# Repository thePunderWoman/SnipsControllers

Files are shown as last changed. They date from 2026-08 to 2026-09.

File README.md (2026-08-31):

<p align="center">
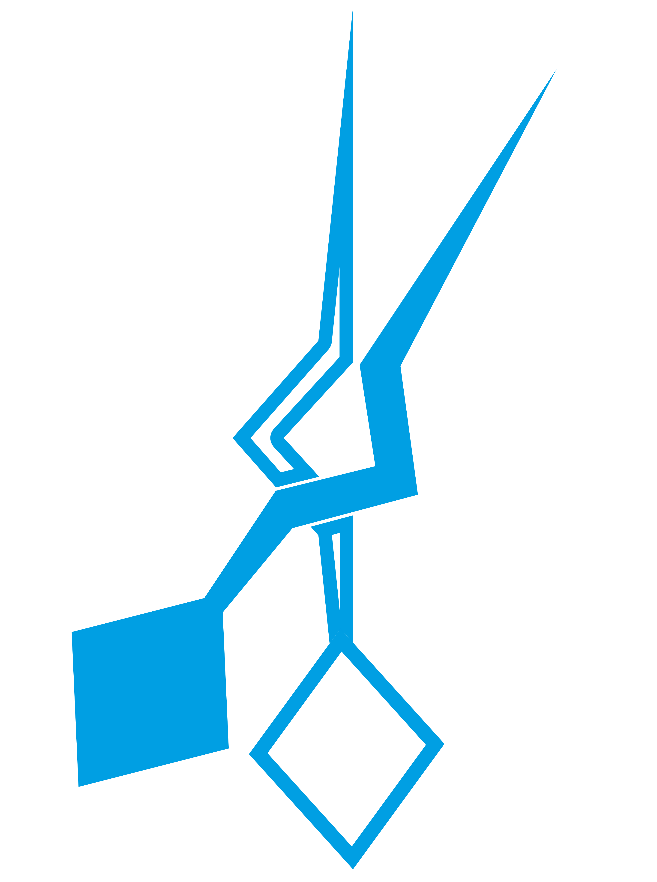
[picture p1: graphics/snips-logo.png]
Snips Controllers logo
  
</p>

<h1 align="center">The Snips Controllers</h1>

<p align="center">
  Wireless handheld controllers for R2-D2 droid operation, built to work with the
  <a href="https://github.com/thePunderWoman/Amidala">Amidala</a> control system and firmware.
</p>

<p align="center">
  <a href="https://github.com/thePunderWoman/SnipsControllers/actions/workflows/ci.yml">
    
  </a>
</p>

## Status

**Awaiting prototype PCBs.**

Schematics, part matching, and layout review are complete; boards are in the ordering/fab pipeline. See [PCB/README.md](PCB/README.md) for the full hardware writeup and [PCB/design-review-2026-08-23.md](PCB/design-review-2026-08-23.md)
for the latest design review. PCBs will likely arrive middle to late September. Once the controllers have been validated, we'll start ordering larger runs and make them available for people to buy.

## What they are

The Snips controllers are dual small handheld controllers for driving your droid
builds. These controllers are intended to be small, but powerful controllers that
can be configured via Amidala to do whatever you prefer to do.

## What they offer

Each Snips controller offers 6 face buttons, 2 side buttons on each side, 1 bumper
button, and a precision hall effect analog trigger. They utilize standard thumbsticks
and are specifically designed to work with either gulikit hall effect or tmr kits,
making sure you have no stick drift over time.

Combining all buttons, including center stick, that's 13 button options per controller. Plus, through Amidala each button can support regular press, alt button press, double press, and long press. All told, you have currently up to **52** different programmable options per controller!

Each controller also has a small OLED screen just above the thumbsticks for as much
info as you'd like to see, like power levels, which hand the controller is for, which
droid, volume levels, etc.

## Communication

These controllers are designed to work with Xbee3 modules for long distance secure
communication, but also, since they are powered by ESP32-S3-WROOM-1 modules, they also
support bluetooth and ESP-Now for connectivity. They will be able to swap between droids, as well.

## Batteries

We're still working on the exact battery spec, but they will either be swappable single 18650 or dual 14500 lithium ion modules. The controllers have a built in charging circuit. So you can charge them via USB-C, or just plain swap mid-event if they run out.

## Case

The controller case, aka how it looks and feels in the hand is still to be designed, but will be open source, allowing you to make it as unique to your build as you'd like.

## Estimated price

This is yet to be determined since we're so early in the prototype stage, but the pricing will be fully transparent. We will likely try to bundle two controllers with an Amidala board, and hopefully close to at cost with a small donation to charity included.

## Repository layout

| Path | Contents |
|---|---|
| [`src/`](src) | ESP32-S3 firmware (PlatformIO) |
| [`test/`](test) | Native unit tests (no hardware required) |
| [`PCB/`](PCB) | KiCad schematics, layout, GPIO reference, and design notes |
| [`scripts/`](scripts) | BOM/part-matching tooling |

## Development

Requires [PlatformIO](https://platformio.org/) (CLI or IDE extension).

```bash
# Build the firmware
pio run

# Run unit tests (no hardware required)
pio test -e native
```

See [CONTRIBUTING.md](CONTRIBUTING.md) for the full contribution workflow.

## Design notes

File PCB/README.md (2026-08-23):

# Snips Controller PCB

A wireless handheld controller for R2-D2 droid operation, designed for use at public events and conventions. Communicates with the droid via XBee3 Zigbee radio in a packetized state-report architecture.

## Hardware Overview

| Component | Part | Notes | Layout diagram |
|---|---|---|---|
| MCU | ESP32-S3-WROOM-1 module | Pre-certified: integrated flash, crystal, WiFi/BT radio + antenna. Same MCU family as Amidala. See `GPIO_table.md` for the full support circuitry | — |
| Display | SSD1306 1.3" OLED | 128x64, monochrome, I2C | — |
| Radio | XBee3 | Zigbee, SPI mode, THT socket (proto) | — |
| Hall trigger | DRV5055A2 | Ratiometric linear hall effect, 3.3V | — |
| Thumbstick | GuliKit hall effect module | Native 3.3V, analog X/Y + click | — |
| Buttons | Omron B3F series | Tactile momentary clicky | — |
| RGB LED | SK6812 NeoPixel-compatible | RMT-driven, 3.3V native, single LED status indicator | — |
| Charger | bq25185 | USB/DC input, power path, 4.2V/500mA | [diagram](diagrams/power_charger_layout.md) |
| Buck | TLV62569 | 3.3V output, 1A | [diagram](diagrams/power_buck_layout.md) |
| Battery | 18650 or 14500 Li-ion | Swappable single cell, TBD empirically | — |
| Power switch | DMG2305UX + 2N7002 | Soft latch, hybrid hardware+firmware | [diagram](diagrams/power_control_layout.md) |

## Layout Diagrams

Suggested top-copper floorplans for the three sheets with real layout
stakes — a switching regulator, a linear charger with a thermal pad, and
the transistor carrying the whole board's current. Each is checked
against the actual component datasheet, not just the schematic. See
[`diagrams/README.md`](diagrams/README.md) for the full list and how the
files are organized.

- [Buck converter](diagrams/power_buck_layout.md) — `power_buck.kicad_sch`
- [Charger](diagrams/power_charger_layout.md) — `power_charger.kicad_sch`
- [Power latch](diagrams/power_control_layout.md) — `power_control.kicad_sch`

## GPIO Assignment

> See `GPIO_table.md` for the full pin-by-pin table, including
> ESP32-S3-WROOM-1 support circuitry — this section is a summary.

### Reserved — Do Not Use
| Pin | Reason |
|---|---|
| 1, 40, 41 | GND |
| 2 | 3V3 |
| 3 (EN) | Reset/enable, pulled up via R_EN_PU |
| 13 (USB_D-) | Native USB |
| 14 (USB_D+) | Native USB |
| 27 (GPIO0/BOOT) | Boot strapping pin, pulled up via R_BOOT_PU + button |
| 26-32 (internal) | Internal SPI flash — not present on this module at all |
| 33-34 (internal) | Not broken out on the WROOM-1 module |
| 8 (GPIO15) | XBee SPI_ATTN — data-ready interrupt |
| 22 (GPIO18) | XBee ON_SLEEP status input |

Usable with care (strapping pins, sampled at boot): 15 (GPIO3), 16 (GPIO46), 26 (GPIO45).
Clean spares (default JTAG): 34-35 (GPIO41-42). 32/33 from the same group are used by BTN_VOL_DN/BTN_VOL_UP.

The module integrates the WiFi/BT radio, antenna, flash, and crystal
internally — no external wireless component, no bit-banged interface
consuming GPIO, unlike the bare-RP2350A design this replaced.

### SPI (XBee)
| Function | Pin |
|---|---|
| XBee SCK | 18 |
| XBee MOSI | 19 |
| XBee MISO | 20 |
| XBee CS | 21 |
| XBee ON_SLEEP | 22 |
| XBee SPI_ATTN | 8 |

### I2C (OLED)
| Function | Pin |
|---|---|
| SDA | 12 |
| SCL | 17 |

### ADC — ADC1 only (ADC2 is unusable while WiFi is active)
| Function | Pin |
|---|---|
| Analog trigger (DRV5055) | 4 |
| Thumbstick X (GuliKit) | 5 |
| Thumbstick Y (GuliKit) | 6 |
| VSYS battery sense | 7 |

### Digital Inputs / Outputs
| Function | Pin | Notes |
|---|---|---|
| Vol up | 33 | Active low, internal pull-up |
| Vol down | 32 | Active low, internal pull-up |
| Trigger up (mirrored VOL pair, opposite-handed variant) | 9 | Active low, internal pull-up |
| Trigger down (mirrored VOL pair, opposite-handed variant) | 10 | Active low, internal pull-up |
| Digital trigger (bumper) | 11 | Active low, internal pull-up |
| Thumbstick click (KEY) | 23 | Active low, internal pull-up |
| Macro buttons 1-6 | 24, 25, 28, 29, 30, 31 | Active low, internal pull-up — direct-wired, no scan matrix |
| Power button sense | 38 | Input, 3-second hold detect |
| Charge status STAT1 | 39 | Open-drain, 10kΩ pull-up to 3V3 |
| Power latch hold | 36 | Output, HIGH on boot to hold latch |
| RGB LED DIN (SK6812) | 37 | RMT-driven |

### Macro Buttons — Direct-Wired, No Scan Matrix
6 macro buttons, each on its own GPIO with an internal pull-up. No
anti-ghosting diodes or scan firmware needed — ESP32-S3-WROOM-1 has
enough spare GPIO (roughly 8) that the 1-pin savings a 2x3 matrix would
give isn't worth the added complexity, unlike the bare-RP2350A design
(only 1 spare pin) this replaced.

### Spare GPIO
Pins 34-35 (default JTAG, clean) and 15/16/26 (strapping, usable with care).
32/33 from the same JTAG group are used by BTN_VOL_DN/BTN_VOL_UP.

---

## MCU Support Circuitry (ESP32-S3-WROOM-1)

Far simpler than the bare-RP2350A design it replaced — the module
integrates flash, crystal, and the WiFi/BT radio + antenna internally.
What's left: EN pull-up, BOOT pull-up + button, USB series resistors,
3V3 decoupling, and the VSYS battery-sense divider — all standard
ESP32-S3 practice, matching Espressif's own reference designs. See
`GPIO_table.md` for the full component list.

**No longer needed at all:** external QSPI flash chip, crystal + load
caps, core-regulator LC filter, ADC_AVDD RC filter, per-pin IOVDD/DVDD
decoupling network, separate wireless module + its bit-banged interface
+ antenna licensing question.

> **Layout note:** the module's footprint includes the required antenna
> keepout area — keep copper/components out of it per the module's
> datasheet. Much simpler than a custom PCB trace antenna, but still a
> real layout-stage requirement.

---

## Passives & Support Components

### Decoupling Caps
| Component | Value | Notes |
|---|---|---|
| DRV5055 VCC | 100nF ceramic | Close to supply pin |
| GuliKit VCC | 100nF ceramic | Close to supply pin |
| SK6812 VCC | 100nF ceramic | Close to supply pin |
| bq25185 VIN | 10µF + 100nF ceramic | X7R/X5R, 25V rated |
| bq25185 SYS | 10µF + 100nF ceramic | X7R/X5R, 25V rated |
| bq25185 BAT | 10µF ceramic | |
| TLV62569 VIN | 10µF ceramic | |
| TLV62569 VOUT | 22µF ceramic | |
| ESP32-S3-WROOM-1 3V3 | 10µF + 100nF ceramic | Standard module decoupling |

### Pull-up Resistors
| Signal | Value | Notes |
|---|---|---|
| bq25185 STAT1 | 10kΩ | Open-drain, pull up to 3V3 |
| bq25185 TS/MR | 10kΩ to GND | REQUIRED if no thermistor — floating = no charging |
| XBee RESET | 10kΩ to 3V3 | Plus 100Ω + 100nF RC filter at pin |
| I2C SDA/SCL | 4.7kΩ | **DNP for prototyping** — Adafruit #938 has onboard pull-ups. Populate only on final PCB with bare OLED panel |
| ESP32-S3 EN | 10kΩ to 3V3 | Reset/enable |
| ESP32-S3 GPIO0/BOOT | 10kΩ to 3V3 | Plus button to GND to force UF2/download mode |

### Series Resistors
| Signal | Value | Notes |
|---|---|---|
| SK6812 DIN (pin 37) | 300–500Ω | Signal integrity, place close to pad |
| USB D+/D- (pins 13/14) | 27Ω | Between module and external USB-C connector |

### Direct Buttons (all of them — no matrix)
No external components needed. Wire to GND; enable ESP32-S3 internal
pull-ups in firmware. Applies to vol up/down, digital trigger, stick
click, and all 6 macro buttons.

### XBee
Refer to AmidalaShield V1.2 for XBee3 support circuitry. THT socket for prototyping; update footprint to SMT module for final PCB if size requires.

Beyond the 4-wire SPI bus (SCK/MOSI/MISO/CS) and RESET, three more pins are
wired per Amidala's actual netlist: DTR tied to GND, ON_SLEEP and SPI_ATTN
to pins 22/8. SPI_ATTN in particular is the XBee's data-ready interrupt —
needed for reliable SPI transfers, not just a nice-to-have.

---

## Communication Architecture

Controllers communicate with the droid via XBee3 in **packetized state-report** mode. The ESP32-S3 firmware reads all inputs locally (button states, ADC values for analog trigger and thumbstick) and assembles them into a structured payload transmitted periodically over SPI to the XBee3 radio. The receiving AmidalaShield deserializes the packet and interprets controller state.

This approach is preferred over per-signal transmission as it is more efficient, easier to deserialize, and robust to timing issues.

### Network Configuration
- Each droid has its own coordinator with a unique PAN ID
- All coordinators share the same AES encryption key
- Controllers are configured as routers
- "Switch droid" functionality is implemented via XBee API commands to leave the current network and rejoin a different PAN ID on demand
- Active droid name and connection status are shown on the OLED display

---

## Bringup Sequence

Recommended bringup order:
1. ESP32-S3-WROOM-1 alone — verify USB enumeration, flash blink sketch, confirm pin 36 latch hold works
2. OLED on I2C — verify I2C on pins 12/17, get something on screen
3. SK6812 RGB LED — verify RMT output on pin 37, cycle colors
4. Buttons — verify direct inputs on pins 9/10/11/23 and all 6 macro buttons (pins 24/25/28/29/30/31)
5. Charge status — verify STAT1 on pin 39 reads correctly
6. DRV5055 + GuliKit thumbstick — verify ADC1 readings on pins 4/5/6
7. XBee over SPI — verify basic communication

---

## Power Architecture

- Battery → bq25185 (charger + power path, 4.2V VBATREG, 500mA) → TLV62569 (3.3V buck) → ESP32-S3-WROOM-1 3V3 and all 3.3V logic
- Power switch: soft latch (DMG2305UX PFET + 2N7002 NFET) controls TLV62569 EN pin
- Boot: press power button → hardware latch enables 3V3 → ESP32-S3-WROOM-1 boots → pin 36 driven HIGH to hold latch
- Shutdown: firmware detects 3-second hold on pin 38 → graceful shutdown → pin 36 LOW → power cut
- bq25185 STAT1 → pin 39 (open-drain, 10kΩ pull-up to 3V3)
- Battery voltage sense → pin 7 via external R_VSYS1/R_VSYS2 divider (reads VSYS/3 via ADC1)
- All logic is 3.3V native — ESP32-S3-WROOM-1, DRV5055, GuliKit thumbstick, SK6812

No firmware ADC-gating workaround needed for battery sense — WiFi is
fully on-die on ESP32-S3 and doesn't share any exposed GPIO/ADC path
with the VSYS sense pin, unlike the old bit-banged RP2350+CYW43439
design.

## Power Management

Firmware implements tiered power saving:
- **Active**: full brightness OLED, normal polling rate
- **Idle (short timeout)**: OLED dimmed via SSD1306 contrast command
- **Idle (long timeout)**: OLED off
- **Sleep**: MCU sleep, wake on any button press via GPIO interrupt

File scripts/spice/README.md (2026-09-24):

# SPICE check for the Power_Control soft-latch

`latch_sim.py` simulates the button, inverter, diode-OR, latch FET and power PMOS from
`PCB/power_control.kicad_sch` and asserts the behavior we need. ERC, DRC and the netlist only prove
the wiring; they cannot show that a gate is driven high enough or that a power-up transient stays
quiet. This was written after exactly that kind of bug got through (see PRs #58-#60).

```sh
python3 scripts/spice/latch_sim.py              # all checks; exit 1 on any failure
python3 scripts/spice/latch_sim.py --cap 0      # without C_LATCH_G1 -> the insertion checks fail
python3 scripts/spice/latch_sim.py --cap 47n    # a smaller cap -> fails the gate-margin check
python3 scripts/spice/latch_sim.py --scenario press
```

It drives `libngspice`, which KiCad bundles at
`/Applications/KiCad/KiCad.app/Contents/PlugIns/sim/libngspice.dylib` (there is no ngspice CLI).
Set `NGSPICE_LIB` to use a different copy. No Python packages are needed.

## Checks

| Scenario | What it asserts |
|---|---|
| `insert` | Battery plugged in with the board off (VSYS 3.0-4.5V, 10us-1ms rise): `PWR_EN` stays under the buck's EN threshold, the latch gate peaks under 0.5V (below the AO3400A's 0.65V minimum threshold), and the board ends off. |
| `press` | A held button turns `PWR_EN` on within 20ms at VSYS 3.0V with worst-case FET thresholds, and at typical/best-case corners. |
| `shutdown` | The 3V3 rail collapsing after shutdown never lifts the latch gate or `PWR_EN`. |

## Keeping it in sync

The netlist is written by hand to mirror the schematic. When `power_control.kicad_sch` changes
(values, a new part on the latch/sense/EN nodes, a different FET), update the constants and topology
at the top of `latch_sim.py` and rerun. Treat a red run as a design problem first and a model problem
second, but do sanity-check the model too: an arbitrary 1uF on the EN pin once produced a fake
100ms glitch.

## What it does not model

- Generic SPICE models, not vendor ones: a 2N3904-family model for the MMBT3904, a fitted BAT54,
  1N4148, and Level-1 MOSFETs at typical and worst-case gate thresholds.
- VSYS is an ideal source with a clean ramp (no battery impedance, hot-plug bounce, or bulk caps).
- The buck's EN pin is just its pin capacitance; the buck, 3V3 loads and ESP32 boot are not simulated,
  so a short `PWR_EN` pulse is judged against the EN threshold only, not against what the MCU would do.
- Temperature, component tolerance and leakage beyond the diode/FET models.

Bench-confirm on the first real board: scope `PWR_EN` on battery insertion, and confirm a held press
latches at low battery.

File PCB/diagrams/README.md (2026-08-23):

# PCB Layout Diagrams

Suggested top-copper floorplans for the sheets in this project with real
layout stakes — tight switching loops, thermal pads, or current-carrying
parts — derived from the schematic plus the actual component datasheets,
not guessed. Model your KiCad layout after these rather than placing
parts from scratch.

## Diagrams

| Diagram | Sheet | Why it needed one |
|---|---|---|
| [Buck converter](power_buck_layout.md) | `power_buck.kicad_sch` | Switching regulator — tight input loop, short switch node, feedback routed clear of noise |
| [Charger](power_charger_layout.md) | `power_charger.kicad_sch` | Linear charger in a WSON-10 — thermal pad via array is the whole story |
| [Power latch](power_control_layout.md) | `power_control.kicad_sch` | One transistor carries the entire board's current; the power button's position is a mechanical constraint, not an electrical one |

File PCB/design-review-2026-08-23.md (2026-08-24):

# SnipsControllers PCB — Design Review
**Date:** 2026-08-23 | **Analyzer:** kicad-happy v2.2.0 | **Run:** 2026-08-23_1949

## Overview

| | |
|---|---|
| **Board** | 35.0 × 99.9mm, 4-layer |
| **Stackup** | F.Cu (signal) / In1.Cu (3V3 plane, 83% fill) / In2.Cu (GND plane, 85% fill) / B.Cu (signal) |
| **Components** | 71 schematic, 81 PCB footprints (includes fiducials and mechanical) |
| **Routing** | Complete — 109 vias, 0 unrouted nets |
| **MPN coverage** | 70/71 (J_STICK1 is a custom part with no standard MPN — expected) |
| **Verification basis** | MPN-level consistency — no datasheets synced yet, so no pin-level or value verification against manufacturer specs |

---

## Schematic

**No errors.** 10 warnings — all either false positives or accepted design decisions (detailed below).

### False positives

**PU-001 — XBee RESET pull-up:** The analyzer flags U_XBEE1 pin RESET for a missing pull-up. This is incorrect — R_XBEE_RST1 pulls XBEE_RESET to 3V3 through XBEE_RST_PU, with R_XBEE_RC1/C_XBEE_RC1 forming a 159Hz debounce RC. Pull-up is present.

**PU-001 — BQ25185 TS/MR:** R_TS1 = 10kΩ to GND is intentional. This disables the NTC thermistor function on the charger. If a battery NTC is added later, replace R_TS1 with a 10kΩ NTC.

**RS-001 — PWR_GATE, PWR_LATCH_G, PWR_BTN_SENSE, PWR_EN, PWR_HOLD, VSYS_SENSE:** These rails are driven by discrete logic (FETs, diodes) or MCU GPIO. The analyzer cannot trace sourcing through passive topology for these nets. Add `PWR_FLAG` symbols if ERC cleanliness is important; no functional issue.

### Accepted open items

**PU-001 — BQ25185 STAT2:** STAT2 (open-drain) → NO_CONNECT. Acceptable if STAT2 status monitoring is not needed. If it causes noise concerns later, add a DNP 4.7kΩ pull-up to 3V3.

**DS-002 — No datasheets synced:** 70/71 MPNs are now populated. Syncing datasheets (via DigiKey/LCSC scripts) would enable pin-level verification and decoupling adequacy checks against manufacturer specs. Not blocking for prototype.

---

## Power Tree

```
VBUS (USB-C J_USB1)
  ├─ D_VBUS_TVS1 (PESD5V0S1BA, SOD-323) → GND   [ESD clamp]
  └─ U_CHG1 (BQ25185DLHR)
       IN=VBUS  →  SYS=VSYS  |  BAT=VBAT ← BT1 (Li-Ion battery)
       R_ISET1=600Ω   (charge current — verify against BQ25185 datasheet)
       R_VSET1=18kΩ   (charge voltage set — verify against datasheet)
       R_TS1=10kΩ→GND (NTC disabled)
       STAT1 → R_STAT1 (10kΩ) → 3V3, read by MCU GPIO1
       STAT2 → NO_CONNECT

VSYS → Power latch
  SW_PWR1 (button) → D_OR1 → PWR_LATCH_G → Q_LATCH1.G (2N7002 NMOS)
  MCU GPIO44 (PWR_HOLD) → D_OR2 → PWR_LATCH_G
  Q_LATCH1.D → PWR_GATE → Q_PWR1.G (DMG2305UX PMOS)
  Q_PWR1: S=VSYS, D=PWR_EN → U_BUCK1.EN
  R_GATE1=100kΩ VSYS→PWR_GATE (pull-up, keeps PMOS off by default)
  R_LATCH_G1=10kΩ PWR_LATCH_G→GND (pull-down, keeps NMOS off by default)

VSYS → U_BUCK1 (TLV62569, switching 500kHz) → 3V3
  R_FB1=255kΩ / R_FB2=56.2kΩ → Vout = 3.322V  (Vref=0.6V)
  L_BUCK1=2.2µH (Bourns SRN4018)
  Cin:  10µF + 10µF + 100nF (VSYS rail)
  Cout: 22µF + 3×10µF + 1µF + 5×100nF + 47pF (3V3 rail)
  Tj=64°C at 25°C ambient, margin 61°C to Tj_max   ✓ thermal OK

3V3 load estimate:
  ESP32-S3-WROOM-1-N8 (U_MCU1)   240mA
  XBee 3 (U_XBEE1)                10mA
  DRV5055A2 (U_HALL1)              5mA
  OLED connector (U_OLED1)        10mA
  ─────────────────────────────────────
  Total                           265mA
```

### Firmware notes

- **PWR_HOLD must be asserted immediately on boot.** GPIO44 defaults to high-impedance. While it floats, D_OR2 does not conduct and the system stays powered only while the button is physically held via D_OR1. Firmware must drive PWR_HOLD high in `app_main()` before yielding to the RTOS scheduler.
- **GPIO44 = U0RXD conflict.** The ESP32-S3 uses GPIO44 as UART0 RX during serial flashing. Configure GPIO44 as a push-pull output only after the UART boot window has closed to avoid conflicting with the programmer's TX line.

---

## Signal Analysis

**USB-C:** CC1/CC2 pull-downs R_CC1=R_CC2=5.1kΩ to GND — correct sink identification. D+/D- connected to MCU GPIO19/20 (native USB PHY) through 27Ω series resistors — appropriate for USB FS.

**SPI (XBee):** MOSI/MISO/SCK/CS on ESP32-S3 hardware SPI pins (GPIO10–13). XBee decoupling: 4×VCC caps (100nF×2, 1µF, 10µF), RC reset filter (159Hz), SPI attention line to MCU GPIO15.

**I2C (OLED):** GPIO8=SDA, GPIO9=SCL. Analyzer did not detect I2C pull-up resistors — verify pull-ups are present (typically 4.7kΩ to 3V3 for 400kHz operation).

**Analog:** TRIG_ANALOG (DRV5055A2 hall sensor) → GPIO4/ADC1_CH3. STICK_X/Y (GuliKit thumbstick) → GPIO5–6/ADC1_CH4–5. VSYS_SENSE (R_VSYS1=200kΩ / R_VSYS2=100kΩ divider, VSYS/3) → GPIO7/ADC1_CH6.

**RGB LED:** D_RGB1 data in from GPIO43 via R_RGB1.

**RC filters:** R_XBEE_RC1/C_XBEE_RC1 at 15.9kHz (SPI line filter), R_XBEE_RST1/C_XBEE_RC1 at 159Hz (reset debounce).

---

## PCB Layout

| Metric | Value | Status |
|---|---|---|
| Board dimensions | 35.0 × 99.9mm | — |
| Copper layers | 4 | — |
| Routing | 100% complete | ✓ |
| DFM tier | Standard | ✓ |
| DRC violations | 0 | ✓ |
| Min track width | 0.2mm | ✓ |
| Min drill | 0.3mm | ✓ |
| Min annular ring | 0.15mm | ✓ |
| Fiducials | ≥1 per face | ✓ |
| Test points | 0% coverage | Open |
| XBee courtyard overlaps | 8 components | Accepted (see below) |
| Edge switch overhangs | 7 instances | Accepted (see below) |

### Accepted placement findings

**XBee courtyard overlaps (PM-001):** C_XBEE_RC1, C_XBEE_VCC1–4, R_XBEE_RC1, R_XBEE_RST1, SW_BOOT1, and REF** (fiducial) all overlap the U_XBEE1 courtyard. Root cause: the XBee footprint courtyard encompasses the RF keepout zone rather than just the physical module outline. The decoupling components are correctly positioned for the module; the courtyard definition is the inaccuracy. If fab-submitted as-is, assembly will not be affected. **Suppress these in DRC** or correct the footprint courtyard to the physical module boundary and enforce the RF keepout separately as a rule area.

**Edge-mounted switches (PM-002):** SW_PWR1 (0.35mm overhang), SW_THR_DN1 / SW_THR_UP1 / SW_TRIG_DIG1 (0.55mm), SW_VOL_DN1 / SW_VOL_UP1 (0.5mm), U_HALL1 (0.27mm from edge), SW_BOOT1 (0.5mm from edge) are all intentionally placed at or near the board edge for a handheld controller form factor. C_OLED_1 (0.8mm) and D_RGB1 (0.5mm) are near-edge warnings. **Suppress these in DRC** with a board-edge clearance exception.

**REF** in PCB not in schematic (XV-001):** Expected — fiducial markers are PCB-only. No action needed.

### Open item

**Test points (TE-001):** 0% net coverage. Recommend adding test points before production on: GND, 3V3, VSYS, VBAT, VBUS, USB_DP_MCU / USB_DM_MCU, SPI_SCK / MOSI / MISO, I2C_SDA / SCL, MCU_EN.

---

## EMC Assessment

This is a handheld consumer device with no FCC/CE certification requirement indicated. EMC findings are noted for awareness; none are blocking for prototype.

**Stackup (SU-001 — false positive):** The analyzer flags F.Cu, In1.Cu, In2.Cu, and B.Cu as all "signal" type and reports adjacent signal layer crosstalk. In reality In1.Cu is a 3V3 copper pour (83% fill) and In2.Cu is a GND copper pour (85% fill). The stackup is correct: signal / power plane / ground plane / signal. KiCad stores copper-pour planes as "signal" type, which confuses the EMC analyzer. These three SU-001 findings can be disregarded.

**Ground plane coverage (GP-001):** Several signals cross areas where the In1.Cu (3V3) and In2.Cu (GND) planes don't fully overlap, creating return current detours. The affected signals are all low-speed (button GPIO, I2C at 400kHz, analog ADC inputs) — radiated risk is low in practice.

| Signal | Coverage | Length | Risk |
|---|---|---|---|
| XBEE_RESET | 25% | 2.6mm | Low (very short trace) |
| BTN_THR_UP | 68% | 24mm | Low (slow GPIO) |
| I2C_SCL | 73% | 19mm | Low (400kHz) |
| BTN_MACRO1 | 75% | 38mm | Low (slow GPIO) |
| TRIG_ANALOG | 77% | 27mm | Low (ADC, slow) |
| STICK_X, BTN_STICK | 80–81% | 20–24mm | Low |
| BTN_THR_DN through BTN_MACRO6 | 82–93% | 33–65mm | Low |
| XBEE_SPI_ATTN, XBee_CS, STAT1 | 86–89% | 81–103mm | Low–Medium |
| STICK_Y, XBEE_ON_SLEEP | 91–93% | 42–93mm | Low |

**Return path stitching (RP-001):** 20+ nets have F.Cu↔B.Cu via transitions without adjacent ground stitching vias. Same root cause as GP-001 — affects the same slow signals. For a non-certified handheld, these can be accepted. If EMC pre-compliance becomes a concern, add a GND stitching via near each layer-transition via on the signals with the lowest coverage.

**SPI_SCK (CK-001, CK-003):** SPI_SCK is fully routed on outer layers (microstrip) and passes within 8.5–9mm of J_STICK1 and J_USB1. At typical SPI frequencies (≤20MHz) this is unlikely to cause coupling issues, but if signal integrity becomes a concern, route SPI_SCK on an inner layer.

**Buck converter harmonics (SW-001):** U_BUCK1 switching at 500kHz produces 117 harmonics in the 30–88MHz band. Inherent to any switching regulator. Add a ferrite bead on the VSYS input to U_BUCK1 if conducted emissions become a concern.

---

## Thermal

| Component | Package | Tj (25°C ambient) | Margin to Tj_max |
|---|---|---|---|
| U_BUCK1 (TLV62569) | SOT-23-5 | 64°C | 61°C |

All other components below thermal threshold. No action needed.

---

## Next Steps Before Ordering

| Priority | Action |
|---|---|
| Recommended | Sync datasheets (`sync_datasheets_digikey.py` or `lcsc`) to enable pin-level verification against manufacturer specs |
| Recommended | Verify I2C pull-up resistors are present on I2C_SDA / I2C_SCL |
| Recommended | Suppress accepted DRC findings (XBee courtyard, edge switches) in KiCad DRC config |
| Optional | Add J_STICK1 MPN (custom part — add an internal part number if one exists) |
| Optional | Add test points before production run |
| Optional | Add PWR_FLAG symbols to clean up ERC |
| Optional | Add DNP pull-up on STAT2 (4.7kΩ to 3V3) |

---

## Skipped Analyses

| Analysis | Reason |
|---|---|
| Pin-level datasheet verification | No datasheets synced (MPNs now available — run sync to enable) |
| SPICE simulation | No ngspice / LTspice / Xyce installed |
| Gerber verification | No gerber files in project directory |
| Component lifecycle audit | Network access or API keys needed; run `analyze_schematic.py --lifecycle` |

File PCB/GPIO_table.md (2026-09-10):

# Snips Controller — ESP32-S3-WROOM-1 GPIO Table

> **⚠ Known kicaddy bug (2026-08-17):** the yaml's `footprint:` field is not
> currently applied by `kicaddy compile` — compiled `.kicad_sch` files have
> blank/wrong Footprint properties for most components right now. The
> `footprint:` values in `snips_controller.yaml` are still accurate as
> documentation of intent; they're just not making it into the compiled
> output yet. **Don't start PCB layout from the current compiled schematic's
> footprints** until this is fixed — assign footprints manually in the
> KiCad GUI in the meantime, or wait for the fix.

> **MCU:** ESP32-S3-WROOM-1 module (pre-certified, integrated flash +
> crystal + WiFi/BT radio + PCB antenna). No external RF design, flash,
> or crystal needed — the module handles all of that internally. Custom
> USB-C for firmware flashing, charging, and future accessory expansion
> (the module's native USB is genuinely exposed, unlike a Pico-family
> module whose USB is hardwired to its own onboard connector).
> Pins referenced by number in the yaml, not name — the module's pins are
> heavily multi-function (e.g. pin 4 is "GPIO4/TOUCH4/ADC1_CH3") and
> numbers are unambiguous. See `MCU_Core` section of `snips_controller.yaml`.

## Reserved / Do Not Use
| Pin | Reason |
|---|---|
| 1, 40, 41 | GND |
| 2 | 3V3 |
| 3 | EN — reset/enable, pulled up via R_EN_PU (10kΩ) |
| 13 | USB_D- (native USB) |
| 14 | USB_D+ (native USB) |
| 27 | GPIO0/BOOT — pulled up via R_BOOT_PU (10kΩ), SW_BOOT pulls low to force UF2/download mode |
| 26-32 (internal) | Internal SPI flash — not present on this symbol/module at all |
| 33-34 (internal) | Exist on the bare ESP32-S3 chip but not broken out on the WROOM-1 module |

**Use with care if ever needed** (strapping pins, sampled at boot — fine
for a static signal, avoid anything that toggles during power-up):
| Pin | Note |
|---|---|
| 15 (GPIO3) | Strapping — JTAG signal source select |
| 16 (GPIO46) | Strapping — boot message control. Used for the QMA6100P accelerometer's INT1 line (see Accelerometer section below) — safe since INT1 stays inactive through boot until firmware configures it. |
| 26 (GPIO45) | Strapping — flash voltage select |

**Spare, no caveats** (default JTAG — fully reusable as plain GPIO if you
don't need hardware debugging):
| Pin | Default function |
|---|---|
| 32 (GPIO39) | MTCK |
| 33 (GPIO40) | MTDO |
| 35 (GPIO42) | MTMS — now used for XBee SLEEP_RQ (see below) |

## XBee Auxiliary Pins
| Pin | Reason |
|---|---|
| 22 (GPIO14) | XBee ON_SLEEP status input |
| 35 (GPIO42) | XBee SLEEP_RQ (DTR) — host-driven pin-sleep request, see below |
| 8 (GPIO15) | XBee SPI_ATTN — data-ready interrupt, needed for reliable SPI transfers |

Pulled directly from Amidala's actual AmidalaShield netlist (IPC-2581
export), not guessed: ON_SLEEP and SPI_ATTN go to host GPIO on that board
too (ESP32 GPIO15/16 there — same MCU family as this board now, so the
pin roles map over conceptually).

DTR diverges from Amidala's netlist on purpose: Amidala ties it straight
to GND (permanently deasserted, no host-commanded sleep). This board
wires it to host GPIO42 instead (see SPI (XBee) table below) so firmware
can pin-sleep the module during low-power mode rather than keeping the
radio powered continuously — see the "Low-Power Mode" rationale in the
Accelerometer section below.

---

## SPI (XBee)
| Function | Pin |
|---|---|
| XBee SCK | 18 (GPIO10) |
| XBee MOSI | 19 (GPIO11) |
| XBee MISO | 20 (GPIO12) |
| XBee CS | 21 (GPIO13) |
| XBee ON_SLEEP | 22 (GPIO14) |
| XBee SPI_ATTN | 8 (GPIO15) |
| XBee SLEEP_RQ (DTR) | 35 (GPIO42) |

## I2C (OLED, QMA6100P accelerometer)
| Function | Pin |
|---|---|
| SDA | 12 (GPIO8) |
| SCL | 17 (GPIO9) |

Shared bus — QMA6100P accelerometer joins at I2C address 0x12 (AD0 tied
to GND), distinct from the OLED's 0x3C. See Accelerometer section below.

## ADC — ADC1 only, see note below
| Function | Pin | Notes |
|---|---|---|
| Analog trigger (DRV5055) | 4 (GPIO4) | ADC1_CH3 |
| Thumbstick X (GuliKit) | 5 (GPIO5) | ADC1_CH4 |
| Thumbstick Y (GuliKit) | 6 (GPIO6) | ADC1_CH5 |
| VSYS battery sense | 7 (GPIO7) | ADC1_CH6, divide-by-3 via R_VSYS1/R_VSYS2 |

> **Why ADC1 only:** ESP32-S3's ADC2 is unusable while WiFi is active,
> and this design keeps WiFi on. All 4 analog signals are deliberately
> placed on ADC1-capable pins to avoid any contention — unlike the old
> RP2350 design, there's no firmware-side gating workaround needed here.

## Digital Inputs / Outputs
| Function | Pin | Notes |
|---|---|---|
| Vol up | 33 (GPIO40) | Internal pull-up, active low |
| Vol down | 32 (GPIO39) | Internal pull-up, active low |
| Trigger up (mirrored VOL pair, opposite-handed variant) | 9 (GPIO16) | Internal pull-up, active low |
| Trigger down (mirrored VOL pair, opposite-handed variant) | 10 (GPIO17) | Internal pull-up, active low |
| Digital trigger (bumper) | 11 (GPIO18) | Internal pull-up, active low |
| Thumbstick click (KEY) | 23 (GPIO21) | Internal pull-up, active low |
| Macro button 1-6 | 24, 25, 28, 29, 30, 31 (GPIO47, 48, 35, 36, 37, 38) | Internal pull-up, active low — direct-wired, no scan matrix |
| Power button sense | 38 (GPIO2) | Input, monitors for 3-second hold |
| Charge status STAT1 (bq25185) | 39 (GPIO1) | Open-drain input, 10kΩ pull-up to 3V3 |
| Charge status STAT2 (bq25185) | 34 (GPIO41) | Open-drain input, 10kΩ pull-up to 3V3 — with STAT1, fully decodes charging/done/fault |
| Power latch hold | 36 (GPIO44) | Output, driven HIGH on boot to hold soft latch |
| RGB LED (WS2812/SK6812) | 37 (GPIO43) | RMT-driven, data line |

## Macro Buttons — Direct-Wired, No Scan Matrix
6 macro buttons, each wired straight to its own GPIO with an internal
pull-up (same pattern as the other direct buttons). No anti-ghosting
diodes, no row/column scan firmware.

**Why not a 2x3 matrix?** The RP2350A design used a matrix because it
only had 1 spare GPIO — a matrix costs 5 pins for 6 buttons instead of 6,
a savings worth the diodes and scan complexity when pins are that scarce.
ESP32-S3-WROOM-1 has roughly 8 pins to spare even after every other
signal is assigned (see below), so that 1-pin savings isn't worth it
anymore — direct wiring is simpler to wire, debug, and reason about.

---

## MCU Support Circuitry (ESP32-S3-WROOM-1)

Far simpler than the bare-RP2350A design it replaced — the module
integrates flash, crystal, and the WiFi/BT radio + antenna internally.
What's left is standard ESP32 practice, matching Espressif's own
reference designs (including their DevKitC boards):

| Function | Components | Notes |
|---|---|---|
| EN pull-up | R_EN_PU (10kΩ) | EN has an internal weak pull-up too; external is standard practice for reliable reset timing |
| BOOT pull-up + button | R_BOOT_PU (10kΩ), SW_BOOT | GPIO0 pulled up, button pulls low to force UF2/download mode at boot — same role as the old RP2350 BOOTSEL button |
| USB series resistors | R_USB_DP/R_USB_DM (27Ω) | Between the module's native USB pins (13/14) and the external USB-C connector |
| 3V3 decoupling | C_3V3_1 (10µF bulk), C_3V3_2 (100nF) | Standard module decoupling |
| VSYS battery sense | R_VSYS1 (200kΩ), R_VSYS2 (100kΩ) | Divide-by-3 into pin 7 (ADC1_CH6) |

**No longer needed at all** (this is the point of the pivot): external
QSPI flash chip, crystal + load caps, RP2350 core-regulator LC filter
(VREG_LX/FB), two-stage ADC_AVDD RC filter, per-pin IOVDD/DVDD
decoupling network, separate wireless module + its bit-banged interface
+ antenna licensing question.

## Wireless — Fully Integrated

WiFi/BT radio, antenna, and RF matching are all internal to the
ESP32-S3-WROOM-1 module — no external wireless component, no bit-banged
interface consuming GPIO, nothing to wire in the schematic at all.

**Layout note:** the module's footprint (Espressif's own official
`Espressif.pretty` library) includes the required antenna keepout area —
keep copper/components out of it per the module's datasheet. Much
simpler than the old Murata design's custom PCB trace antenna, but still
a real layout-stage requirement, not just a schematic one.

---

## Passives & Support Components

### Decoupling Caps
| Component | Value | Notes |
|---|---|---|
| DRV5055 VCC | 100nF ceramic | Close to supply pin |
| GuliKit VCC | 100nF ceramic | Close to supply pin |
| WS2812/SK6812 VCC | 100nF ceramic | Close to supply pin |

### Pull-up Resistors
| Signal | Value | Notes |
|---|---|---|
| bq25185 STAT1 pin | 10kΩ | Open-drain, pull up to 3V3 |
| bq25185 STAT2 pin | 10kΩ | Open-drain, pull up to 3V3 |
| I2C SDA/SCL | 4.7kΩ | **DNP for prototyping** — Adafruit #938 has onboard pull-ups. Populate only on final PCB with bare OLED panel |

### Series Resistors
| Signal | Value | Notes |
|---|---|---|
| RGB DIN (pin 37) | 300–500Ω | Signal integrity protection, standard NeoPixel/SK6812 best practice |

### Buttons (all direct-wired, no matrix)
No external components needed — ESP32-S3 internal pull-ups enabled in
firmware, wire to GND. Applies to vol up/down, digital trigger, stick
click, and all 6 macro buttons.

### XBee
Reusing Amidala's verified `XB3-24Z8UT-J` symbol (`PCB/libraries/Xbee3.kicad_sym`).
THT socket footprint used for prototyping; SMT module footprint TBD for final PCB.

Beyond the 4-wire SPI bus (SCK/MOSI/MISO/CS) and RESET, three more pins are
wired per Amidala's actual netlist: DTR tied to GND, ON_SLEEP and SPI_ATTN
to pins 22/8. SPI_ATTN in particular is the XBee's data-ready interrupt —
needed for reliable SPI transfers, not just a nice-to-have.

SPI_ATTN also doubles as the module's BOOTMODE strap; Digi's XBee3 Hardware
Reference Manual (doc 90001543) says not to let it be tied/pulled low at
reset. R_XBEE_ATTN_PU1 (10kΩ to 3V3) holds it high before firmware
configures the pin, same pattern as R_XBEE_RST1 on RESET.

VCC decoupling: 100nF + 1µF + 47pF + 10µF (C_XBEE_VCC1-4), per the Digi
XBee3 RF Module Hardware Reference Manual (doc 90001543, p.52) rather than
guessed — the manual calls for 1.0µF + 47pF near VCC plus a 10µF, placed
smallest-value-closest to the module. AmidalaShield's schematic used 8.2pF
here instead of 47pF, which the current XBee3-specific manual doesn't
support (that value traces to older XBee/S2C-family guidance); corrected
here rather than copied.

### Power Control Circuit
See power control section of schematic. Uses pin 38 (power button sense
input) and pin 36 (latch hold output). Pin 36 must be driven HIGH as the
very first instruction in firmware or power will cut on button release.

### Battery Voltage Sense
Pin 7 (ADC1_CH6) reads VSYS/3 via an external R_VSYS1/R_VSYS2 divider —
same role as the RP2350 design's divider, still needed since
ESP32-S3-WROOM-1 has no VSYS-style pin of its own either. bq25185 STAT1
(pin 39) and STAT2 (pin 34) together fully decode the charger's state:
charging, done, recoverable fault, or latched fault — see the bq25185
datasheet's status pin table.

No firmware ADC-gating workaround needed here (unlike the old bit-banged
RP2350+CYW43439 design) — WiFi is fully on-die and doesn't share any
exposed GPIO/ADC path with this sense pin.

---

## Accelerometer (QMA6100P) — Low-Power Mode

Added to support an auto low-power mode: after a configurable idle
timeout (no buttons, no motion), firmware turns the OLED off and puts
the XBee into pin sleep (see XBee SLEEP_RQ above) instead of keeping the
radio powered continuously; after a much longer configurable timeout, it
does a full soft-latch power-off. Button or accelerometer motion wakes
the device back up.

**Why QMA6100P:** chosen over MSA311/LIS3DH/ADXL345/MPU-6050 after
checking JLCPCB's actual parts library (as of 2026-09) — none of the
candidates are Basic-library (that framing was wrong when first floated;
corrected after verifying against JLCPCB's own part pages and the
community-maintained `jlcpcb-parts-database` mirror of it), so library
tier was a wash. QMA6100P won on the remaining criteria: cheapest
($0.61 @1pc vs $1.88 LIS3DH / $5.98 ADXL345, LCSC pricing), smallest
(2x2x0.95mm, tied with MSA311), and by far the lowest standby current
(500nA typ., vs ~2µA+ for the alternatives) — the one spec that matters
most here, since this chip has to stay active watching for motion
through the entire low-power period. It also exposes real hardware
any-motion/no-motion interrupts (not just raw acceleration), which is
what makes MCU light-sleep-and-wake-on-interrupt possible instead of
busy-polling. Source: QST "QMA6100P Preliminary Datasheet" (Doc #13-52-20,
Rev A1).

**I2C wiring** (per the datasheet's Figure 4, I2C Single Supply
Connection): shares the existing OLED bus (GPIO8/9).
| QMA6100P pin | Connection |
|---|---|
| AD0 (1) | GND — sets I2C address to 0x12 |
| SDX (2) | I2C_SDA (shared with OLED) |
| VDD (3) | 3V3 |
| RESV1 (4) | GND |
| INT1 (5) | Host GPIO46 (pin 16) — see Reserved/Do Not Use above |
| INT2 (6) | Unused |
| NC (7) | No connect |
| GNDIO (8) | GND |
| GND (9) | GND |
| SENB (10) | 3V3 — selects I2C protocol (tied high rather than left floating) |
| RESV2 (11) | GND |
| SCX (12) | I2C_SCL (shared with OLED) |

Decoupling per the datasheet's Figure 4 reference schematic: three caps
on VDD (10nF, 100pF, 2.2nF) rather than this board's usual single
100nF — **the two smallest values are a best-effort read of small print
in a preliminary-datasheet figure and should be visually re-checked
against the datasheet before fab.**

**Status: in the schematic/yaml**, on its own `Accelerometer` sheet
(`PCB/accelerometer.kicad_sch`), wired into `snips_controller.yaml`, with
a hand-authored symbol + footprint (`SnipsControllers_Custom:QMA6100P`) —
pad geometry pulled from JLCPCB/LCSC's own EasyEDA component data (LCSC
C2887190) rather than estimated from the datasheet's low-resolution
mechanical drawing. ERC-clean (`kicad-cli sch erc`, 0 violations).
**Still needs the user's physical continuity check against the real part
before fab** — same outstanding step as the GuliKit hallstick footprint.

---

## Spare GPIO
Pins 32/33 (GPIO39/40, default JTAG) — used by BTN_VOL_DN/BTN_VOL_UP.
Pin 34 (GPIO41, default JTAG) — used by bq25185 STAT2.
Pin 35 (GPIO42, default JTAG) — used by XBee SLEEP_RQ (DTR).
Pin 15, 26 (GPIO3/45) — usable, but strapping pins, best for a
static/non-boot-critical signal.
Pin 16 (GPIO46) — strapping pin, reserved for the QMA6100P accelerometer's
INT1 (not yet wired in the schematic — see Accelerometer section above).

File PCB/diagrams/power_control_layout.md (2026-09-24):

# Half of this circuit is electrical, half is where your thumb goes

*PCB layout reference · soft-latch power switch*

Q_PWR1 carries the entire board's current — every milliamp the ESP32, XBee, OLED, and everything else draws passes through one SOT-23 PMOS. But the layout-driving constraint here isn't electrical at all: SW_PWR1 is a physical button that has to land under a hole in your enclosure.

**Source:** `PCB/power_control.kicad_sch` &nbsp;·&nbsp; **Nets:** VSYS → PWR_EN &nbsp;·&nbsp; **Package:** SOT-23 ×3, SOD-123 ×2, SOT-323 ×1

## What's on this sheet

A press-to-start, software-held latch: the button turns the board on, the MCU has to grab the hold line before the button is released, and either side of a diode-OR can keep power on. A small transistor inverter (R_INV_BASE1 / Q_INV1 / R_INV_PU1) sits between the button and that diode-OR — see callout F for why it can't just tap the button's sense line directly, and callout D for why `R_LATCH_G1` is 1MΩ rather than 10kΩ.

| Ref | Value | Footprint | Role |
|---|---|---|---|
| Q_PWR1 | AO3401A | SOT-23 | Main power switch — VSYS to PWR_EN, carries full system current |
| R_PWR_EN_PD1 | 100kΩ | 0402 | `PWR_EN` pull-down to GND — the buck's EN pin has no internal bias and must not be left floating (callout G) |
| Q_LATCH1 | AO3400A | SOT-23 | Pulls Q_PWR1's gate low to turn it on; low-Vth (≤1.45V) so a press still turns it on at the bottom of the battery range (callout D) |
| D_OR1 / D_OR2 | 1N4148W | SOD-123 | Diode-OR: `PWR_BTN_TRIGGER` (actual button press, via the inverter) or MCU hold, either one latches power on |
| R_GATE1 | 100kΩ | 0402 | Q_PWR1 gate pull-up — off by default |
| R_LATCH_G1 | 1MΩ | 0402 | Q_LATCH1 gate pull-down — off by default; sized to not starve the diode-OR's drive (callout D) |
| C_LATCH_G1 | 100nF | 0402 | Latch-gate filter — keeps the ~2ms battery-insertion transient from lifting `PWR_LATCH_G` (callout I) |
| R_BTN_PU1 | 100kΩ | 0402 | Button sense pull-up to **3V3** (not VSYS) — MCU reads pressed (0V) vs idle (3.3V); callout H |
| R_INV_BASE1 | 100kΩ | 0402 | Dedicated VSYS pull-up for Q_INV1's base — decoupled from `PWR_BTN_SENSE` (callout F) |
| D_INV_ISO1 | BAT54W-7-F | SOT-323 | Schottky isolator: lets a press pull Q_INV1's base low without loading `PWR_BTN_SENSE` |
| Q_INV1 | MMBT3904 | SOT-23 | Inverter: idle (button up) holds `PWR_BTN_TRIGGER` low; pressed lets `R_INV_PU1` pull it high |
| R_INV_PU1 | 100kΩ | 0402 | `PWR_BTN_TRIGGER` pull-up to VSYS — the inverter's collector load |
| C_DBNC1 | 100nF | 0402 | Button debounce, right at the switch |
| SW_PWR1 | Alps SKRTLAE010 | SMD tactile | Physical power button — must reach the enclosure surface |

## Suggested floorplan

Top copper layer. The VSYS→PWR_EN path runs straight across the top as one thick lane; the latch logic hangs underneath it as a compact, low-current block; the inverter sits just below the button's sense line, on the way to the diode-OR; the button sits wherever your enclosure needs it to.

![Top-down PCB floorplan for the soft-latch power switch, showing VSYS entering the PMOS source and exiting the drain as PWR_EN in one straight lane across the top, the NMOS latch and diode-OR logic clustered in a compact low-current block beneath it, a small transistor inverter between the button's sense line and the diode-OR so only an actual press (not the button's idle level) can trigger the latch, and the physical power button placed near the board edge with its debounce capacitor right at its pins.](power_control_layout.svg)

*Top-layer placement for the soft-latch switch. **Gold copper** is the VSYS→PWR_EN power path; **pale blue** is the low-current gate-drive, sense, inverter, and control logic; rings mark vias to the ground plane.*

- 🟨 Power copper (VSYS, PWR_EN)
- 🟦 Gate-drive / sense / inverter / control
- ⚪ Via to GND plane

## Why it's arranged this way

| | |
|---|---|
| **A** | **Q_PWR1 is the one part on this sheet that isn't low-current.** Every downstream milliamp — MCU, XBee, OLED, everything — flows through its source-drain path. AO3401A's RDS(on) (<60mΩ at 4.5V gate drive, <85mΩ at 2.5V) keeps drop and heat trivial at this board's current budget, but a SOT-23 has no separate thermal pad — the source/drain copper itself is the heatsink, so give those pads real copper, not just a skinny trace. |
| **B** | **SW_PWR1's position isn't yours to optimize electrically.** It has to land under a hole in whatever enclosure this board sits in — mechanical placement drives this part, and the rest of the latch logic has to route to wherever that ends up, not the other way around. |
| **C** | **C_DBNC1 sits right on the switch's own pins.** Same principle as the charger's pushbutton guidance in its own datasheet: the debounce cap does its job by being close to the contact bounce it's filtering, not by being close to anything else. |
| **D** | **The diode-OR and its pull-down are one compact decision node — and R_LATCH_G1's value is load-bearing, not incidental.** D_OR1, D_OR2, R_LATCH_G1, and Q_LATCH1's gate all meet at PWR_LATCH_G. A press only drives this node through `R_INV_PU1` (100kΩ) and a diode drop — with the original 10kΩ pull-down, that divider left barely 0.3V at Q_LATCH1's gate, nowhere near enough to turn it on. Raised to 1MΩ, the same divider delivers ~2.4V at the bottom of the battery range (VSYS≈3.0V, modelling a real ~0.35V diode drop at µA currents) up to ~3.5V at full charge, without adding any idle current (that's set by `R_INV_PU1`, untouched). A 2N7002's worst-case threshold is 2.5V, which left no margin at the bottom, so `Q_LATCH1` is an AO3400A (Vgs(th) ≤1.45V): at least ~1V of overdrive everywhere. Keeping this cluster tight matters less for noise than for just keeping the logic legible on the board. |
| **E** | **PWR_HOLD arriving late is a hard failure, not a glitch.** Per this project's own GPIO notes, pin 36 (PWR_HOLD) must go high as the MCU's very first instruction — release the button before that happens and R_LATCH_G1's pull-down turns everything back off. Not a layout fix, but it's the reason D_OR2's path exists at all. |
| **F** | **D_OR1 can't read `PWR_BTN_SENSE` directly — found the hard way, on real hardware.** The original design had `R_BTN_PU1` (to VSYS) and a since-removed `R_PWR_SENSE1` (to GND) both on that node, dividing it to roughly half VSYS at idle — comfortably above a diode's ~0.6V forward threshold, so `D_OR1` was forward-biased (and the board powered on) the instant a battery was plugged in, button or no button. The inverter fixes this properly instead of just retuning the divider: idle, `Q_INV1` is on and holds `PWR_BTN_TRIGGER` at GND; pressed, it turns off and `R_INV_PU1` pulls `PWR_BTN_TRIGGER` to VSYS. Only a real press can forward-bias `D_OR1` now. Keep this block close to `D_OR1` — it's parts serving one signal, not worth spreading out.<br><br>**Second-order bug, found the same way:** the inverter's own base resistor originally tapped `PWR_BTN_SENSE` directly, in series with `R_BTN_PU1` — stealing enough idle base current to sag the MCU's own button-read node to ~1V instead of near-VSYS. `R_INV_BASE1` is now its own dedicated 100kΩ pull-up straight to VSYS (not sharing current with `R_BTN_PU1`), and `D_INV_ISO1` (a Schottky, chosen specifically for its lower forward drop than Q_INV1's own base-emitter junction) lets a press still pull the base low without ever loading `PWR_BTN_SENSE`. |
| **G** | **`PWR_EN` had no defined rest state — TI's own datasheet says not to do this.** `Q_PWR1`'s drain feeds the buck's EN pin directly, with nothing else on that node. TLV62569's EN pin is a bare comparator input with no internal pull ("Do not leave floating" per its datasheet) — with `Q_PWR1` off, EN was held by MOSFET/input leakage alone, no guaranteed logic level. `R_PWR_EN_PD1` (100kΩ to GND) fixes it: negligible loading when `Q_PWR1`'s tens-of-mΩ RDS(on) is driving EN high, solid GND the instant it's off. |
| **H** | **`PWR_BTN_SENSE` must never sit above the MCU's rail.** It lands directly on GPIO2 (pin 38), whose ceiling is VDD + 0.3V (~3.6V), but `R_BTN_PU1` used to pull it to VSYS — up to ~4.5V on USB, and it back-fed the unpowered 3V3 rail through the pin's clamp diode whenever the MCU was off. Since `R_INV_BASE1` gave the inverter its own VSYS pull-up (callout F), `R_BTN_PU1` no longer has to supply the inverter, so it now pulls to 3V3: idle reads 3.3V, and with the MCU off the node is simply unpowered instead of leaking into the rail. |
| **I** | **Battery insertion used to blip `PWR_EN` for ~2ms — found in simulation, since no board existed to bench-test.** When VSYS first appears, `Q_INV1` isn't conducting yet: its base current is diverted through `D_INV_ISO1` into the discharged `C_DBNC1` until that charges to ~0.4V. For that ~1–2ms `PWR_BTN_TRIGGER` follows VSYS, `PWR_LATCH_G` rises to ~VSYS−0.6V, and `Q_PWR1` briefly enables the buck. `C_LATCH_G1` (100nF against the 100kΩ pull-up) makes the gate rise slowly enough that the transient peaks at ~0.3V — well under the AO3400A's minimum threshold — at the cost of 4–8ms of press latency, and it gives release a little extra hold time. Keep it right at `PWR_LATCH_G`. |

## Routing priority

The button's position is fixed by the enclosure before you start — everything else routes around it.

1. Place SW_PWR1 wherever the enclosure cutout requires; that position is a constraint, not a choice.
2. Put C_DBNC1 directly on SW_PWR1's sense pin before routing anything else nearby.
3. Route the VSYS→Q_PWR1→PWR_EN lane as one straight, generously-wide path across the board.
4. Cluster Q_LATCH1, R_GATE1, R_LATCH_G1, D_OR1, and D_OR2 into one compact low-current block under the main lane.
5. Keep R_INV_BASE1, D_INV_ISO1, Q_INV1, and R_INV_PU1 together as their own small block, close to D_OR1 — they're a single-purpose inverter, not independent parts.
6. Bring PWR_BTN_SENSE and PWR_HOLD in from wherever the MCU sheet actually sits — these are off-sheet nets, not local components.
7. Drop `R_PWR_EN_PD1` right at Q_PWR1's drain, on the way to `PWR_EN` leaving the sheet — it's a bias resistor for that pin, not an independent part.
8. Put `C_LATCH_G1` on the `PWR_LATCH_G` node next to `R_LATCH_G1` and `Q_LATCH1`'s gate, with a short GND return.

> **Checked, not just assumed:** AO3401A is rated for 4A continuous with <60mΩ RDS(on) at 4.5V gate drive in this SOT-23 package — comfortably oversized for a handheld controller's sub-2A system budget, so this isn't a thermal risk the way the charger's WSON is. MMBT3904 is a general-purpose small-signal part switching microamps here (just enough to bias a diode) — nowhere near its ratings, no thermal consideration needed. BAT54W-7-F's job is purely to isolate two nodes at sub-1V forward drop, also nowhere near its ratings. Connectivity alone (ERC, netlist, DRC) doesn't catch bad DC bias points — the `R_LATCH_G1`/`PWR_BTN_SENSE` loading bugs in callouts D and F, and the floating `PWR_EN` in callout G, all passed every connectivity check and were only found by actually working through the bias/divider math or reading the driven IC's own datasheet, so don't treat a clean ERC/DRC as proof a gate-drive, sense, or enable network will behave.

---
*Generated from `PCB/power_control.kicad_sch` — a placement reference, not a manufacturing drawing. Model your actual footprints and DRC against your fab's rules. A richer standalone version with the full interactive design lives in [power_control_layout.html](power_control_layout.html).*

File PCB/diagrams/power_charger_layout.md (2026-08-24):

# The charger's whole story is thermal, not noise

*PCB layout reference · linear Li-ion charger*

U_CHG1 (BQ25185) is a linear charger — no inductor, no switch node. The layout problem isn't EMI, it's getting heat out of a 2×3mm WSON-10 package while keeping three separate power nets short. Values below are verified against TI's own datasheet, not estimated.

**Source:** `PCB/power_charger.kicad_sch` &nbsp;·&nbsp; **Nets:** VBUS → VSYS / VBAT &nbsp;·&nbsp; **Package:** WSON-10

## What's on this sheet

Eleven parts. Every setting resistor's effect is confirmed against the BQ25185 datasheet (SLUSF65A), not assumed.

| Ref | Value | Footprint | Role |
|---|---|---|---|
| U_CHG1 | BQ25185DLHR | WSON-10 | Linear Li-ion charger + power path, 1A max |
| C_VIN_1 / C_VIN_2 | 10µF / 100nF | 0805 / 0402 | IN decoupling — right at the VBUS pin |
| C_SYS_1 / C_SYS_2 | 10µF / 100nF | 0805 / 0402 | SYS decoupling — this feeds the whole board |
| C_BAT1 | 10µF | 0805 | BAT decoupling, right at the battery pin |
| R_ISET1 | 600Ω | 0402 | Sets ICHG ≈ 500mA (TI-tested value, table 6.5) |
| R_VSET1 | 18kΩ | 0402 | Sets 500mA input limit + 4.2V VBATREG (table 7-1) |
| R_TS1 | 10kΩ | 0402 | Disables TS/battery-NTC monitoring, per datasheet §8.3.9 |
| R_STAT1 | 10kΩ | 0402 | Open-drain STAT1 pull-up to 3V3 |
| R_STAT2 | 10kΩ | 0402 | Open-drain STAT2 pull-up to 3V3 — with STAT1, fully decodes charging/done/fault |

## Suggested floorplan

IN and the SYS/BAT pair sit on opposite edges of the package — a genuine gift from the pinout. Route VBUS straight through from one side to SYS/VBAT on the other and nothing has to double back.

![Top-down PCB floorplan for the BQ25185 linear charger, showing VBUS entering the IN pin on the right, VSYS and VBAT exiting the SYS/BAT pins on the left, decoupling capacitors placed directly at each of those three pins, the ISET/VSET/TS setting resistors clustered tightly on the analog side, STAT1 and STAT2 pull-ups routed out to the MCU on opposite sides of the package, and a via array under the center thermal pad tying it to the ground plane.](power_charger_layout.svg)

*Top-layer placement for U_CHG1. **Gold copper** carries VBUS/VSYS/VBAT power; **pale blue** carries the low-current setting and status signals; rings mark vias to the ground plane. IN sits on the right, SYS/BAT on the left — route the power path straight through rather than doubling back.*

- 🟨 Power copper (VBUS, VSYS, VBAT)
- 🟦 Setting / status signal
- ⚪ Via to GND plane

## Why it's arranged this way

| | |
|---|---|
| **A** | **The thermal pad is the real story here.** This is a linear charger — every volt it drops between IN/SYS/BAT and whatever it's not dropping across the battery becomes heat inside a 2×3mm package. TI's WSON layout guidance calls for 4–6 vias under the pad at ≤0.3mm diameter, ~1mm spacing; the stock footprint in this library only places 2. Add the rest before fab. |
| **B** | **IN, SYS, and BAT each get their own decoupling, right at their own pin.** TI's datasheet layout guidelines (§8.4.1) say it plainly: place the IN, SYS, and BAT capacitors as close as possible to the device — these are three separate short loops, not one shared input loop like a switcher would have. |
| **C** | **VBUS in on the right, VSYS out on the left — no doubling back.** The package puts IN on one edge and SYS/BAT on the opposite edge. That's not a layout choice, it's a gift from the pinout: route the power path straight through and every trace is as short as it can be. |
| **D** | **ISET especially wants a short, direct trace.** R_ISET1 sets the actual charge current (ICHG = K<sub>ISET</sub>/R<sub>ISET</sub>, K≈300AΩ) — at 600Ω that's ≈500mA, matching TI's own tested value for this exact resistance. Stray resistance or noise pickup on this trace shows up directly as charge-current error. |
| **E** | **GND pin and thermal pad share one solid pour.** TI's guideline is explicit: "a solid ground plane tied to the GND pin and thermal pad should be used" — not two separate ground fills stitched together, one plane doing both jobs. |
| — | **STAT1 and STAT2 exit on opposite sides of the package, because that's where their pins are.** STAT1 (pin 9) is right next to IN on the right; STAT2 (pin 3) is on the left, next to SYS/BAT. Individually they're each still a short, direct pull-up-to-pin trace — the split just reflects the pinout, not a routing choice. Together they let firmware fully decode charging vs. done vs. fault instead of just charging-vs-not. |

## Routing priority

Do it roughly in this order — the thermal pad and its via array need the most freedom, so give them first pick of the copper underneath the part.

1. Place U_CHG1, then lay out the thermal-pad via array before anything else claims that space (aim for 4–6 vias, not the footprint's stock 2).
2. Butt C_VIN_1/C_VIN_2 against the IN pin, C_SYS_1/C_SYS_2 against SYS, and C_BAT1 against BAT — three independent short loops.
3. Route VBUS in from one edge and VSYS/VBAT out the opposite edge, straight through.
4. Cluster R_ISET1, R_VSET1, R_TS1, and R_STAT2 tight against their pins on the analog side — keep them clear of the power copper.
5. Pour ground last, tying the GND pin, the thermal pad array, and every decoupling cap's return into one plane.

> **Verified against TI datasheet SLUSF65A:** R_ISET1 (600Ω) → ICHG ≈ 500mA is one of TI's own named test conditions, not an estimate. R_VSET1 (18kΩ) maps to Table 7-1 exactly: 500mA input current limit, 4.2V battery regulation, 3.0V precharge threshold — standard single-cell Li-ion settings. R_TS1 (10kΩ) matches TI's own instruction verbatim: "if the TS function is not required, connect a 10kΩ resistor from the TS/MR pin to GND." Nothing on this sheet needed correcting.

---
*Generated from `PCB/power_charger.kicad_sch` — a placement reference, not a manufacturing drawing. Model your actual footprints and DRC against your fab's rules. A richer standalone version with the full interactive design lives in [power_charger_layout.html](power_charger_layout.html).*

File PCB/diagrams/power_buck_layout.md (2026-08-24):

# Where every part in the buck stage wants to sit

*PCB layout reference · synchronous buck*

U_BUCK1 (TLV62569DBV) switches at ~2–3 MHz and delivers up to 2A — placement determines whether it's quiet or noisy. This maps the schematic to a suggested top-copper floorplan you can model your PCB after.

**Source:** `PCB/power_buck.kicad_sch` &nbsp;·&nbsp; **Nets:** VSYS → 3V3 &nbsp;·&nbsp; **Package:** SOT-23-5

## What's on this sheet

Six parts, one power stage. Values as drawn in the schematic.

| Ref | Value | Footprint | Role |
|---|---|---|---|
| U_BUCK1 | TLV62569DBV | SOT-23-5 | Synchronous buck IC, 2A, adjustable 0.6–5.5V out |
| C_BUCK_IN1 | 10µF | 0805 | Input bulk/decoupling — absorbs the IC's pulsed input current |
| L_BUCK1 | 2.2µH | Bourns SRN4018 | Power inductor |
| C_BUCK_OUT1 | 22µF | 0805 | Output filter cap |
| R_FB1 | 255kΩ | 0402 | Feedback divider, VOUT side |
| R_FB2 | 56.2kΩ | 0402 | Feedback divider, GND side |

## Suggested floorplan

Top copper layer, drawn roughly to scale. Trace weight signals current, not just wire — the input loop and switch node get thick, short, direct copper; the feedback path gets thin copper routed the long way around to stay quiet.

Top-down PCB floorplan for the TLV62569 buck stage, showing the input capacitor and IC placed in a tight loop, the inductor placed directly off the switch pin, the output capacitor next to the inductor, and the feedback divider routed on a separate quiet path back to the IC's FB pin, away from the 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

*Top-layer placement and routing for U_BUCK1, sized roughly to real footprint proportions. **Gold copper** carries the input, switch, and output power path; **pale blue** carries the low-current FB and EN signals; rings mark vias dropping straight to the ground plane. Board edges shown are the crop of this local zone, not the full board.*

- 🟨 Power copper (VSYS, SW, VOUT)
- 🟦 Feedback / enable signal
- ⚪ Via to GND plane

## Why it's arranged this way

| | |
|---|---|
| **A** | **Input loop stays tiny.** C_BUCK_IN1 sits directly on top of VIN, with its ground pad dropping straight to a via. VIN, the cap, and the return path form the loop the IC's fast input-current pulses actually flow through — keep its area small and this is one of the highest-leverage placements on the board for both efficiency and radiated noise. |
| **B** | **SW node is short and alone.** The trace from pin 3 to L_BUCK1 carries the full switched current at the IC's switching frequency and acts as an antenna if it's long or fat. Keep it the shortest, most direct copper on the board and don't route anything else near or under it. |
| **C** | **Feedback taps the output cap, not the inductor.** R_FB1 picks up VOUT right at C_BUCK_OUT1's pad — the point that's actually regulated — instead of further upstream where switching ripple is still settling. |
| **D** | **Every return pad gets its own via.** C_BUCK_IN1, U_BUCK1, C_BUCK_OUT1, and R_FB2 each drop to the ground plane independently rather than daisy-chaining through each other on the top layer, so switching return current can't inject noise into the quiet feedback ground. |
| **E** | **FB takes the long way home.** Once through the divider, the FB signal is thin and high-impedance — a few millivolts of coupled switching noise here shows up directly as output ripple. It's routed around the left side of the IC, clear of the SW/L1 copper, even though that's a longer path. |

## Routing order

If you're placing copper by hand, do it roughly in this order — later steps have less freedom once earlier ones are locked in.

1. Pour ground on the bottom layer first; treat everything else as carving space out of it.
2. Place U_BUCK1, then butt C_BUCK_IN1 against its VIN pin before anything else claims that space.
3. Route SW to L_BUCK1 — shortest path wins, width sized for 2A.
4. Place C_BUCK_OUT1 off the inductor's far pad, then fan VOUT out to the load.
5. Tap FB at C_BUCK_OUT1, place R_FB1/R_FB2 close together, route the sense line back around the IC last — by now you know exactly what copper it has to avoid.
6. Stitch a via at every ground pad (C_IN, IC, C_OUT, R_FB2).

> **Fixed:** R_FB1 was originally 100kΩ, which works out to 1.67V at the TLV62569's 0.6V typical reference (V<sub>OUT</sub> = 0.6 × (1 + R_FB1⁄R_FB2)) — not the 3.3V the "3V3" net label promised. Verified against TI's datasheet (SLVSDG1C): VFB = 0.6V typ (0.588–0.612V), confirmed by their own 200k/100k → 1.8V reference design. R_FB1 is now 255kΩ (nearest E96), giving 3.322V with R_FB2 unchanged at 56.2kΩ.

---
*Generated from `PCB/power_buck.kicad_sch` — a placement reference, not a manufacturing drawing. Model your actual footprints and DRC against your fab's rules. A richer standalone version with the full interactive design lives in [power_buck_layout.html](power_buck_layout.html).*

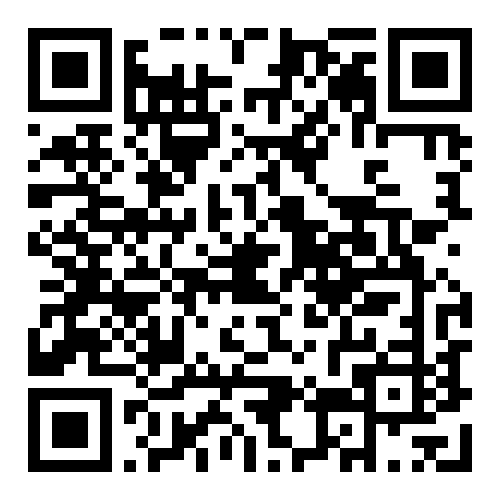
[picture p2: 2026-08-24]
graphics/snips-github-qr.png

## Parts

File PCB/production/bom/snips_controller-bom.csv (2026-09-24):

Id | Designator | Footprint | Quantity | Designation | Supplier and ref
1 | BT1 | JST_PH_S2B-PH-K_1x02_P2.00mm_Horizontal | 1 | PH 2-pin battery RIGHT-ANGLE HORIZONTAL | S2B-PH-K(LF)(SN) | JST | THT right-angle horizontal 2.00mm
2 | C_3V3_1, C_XBEE_VCC4 | C_0603_1608Metric | 2 | 10µF | CL10A106KP8NNNC | Samsung Electro-Mechanics | 0603
3 | C_3V3_2, C_DBNC1, C_HALL1, C_LATCH_G1, C_OLED_2, C_RGB1, C_STICK1, C_SYS_2, C_VIN_2, C_XBEE_RC1, C_XBEE_VCC1 | C_0402_1005Metric | 11 | 100nF | CL05B104KO5NNNC | Samsung Electro-Mechanics | 0402
4 | C_3V3_3 | C_0402_1005Metric | 1 | 39pF | CC0402JRNPO9BN390 | Yageo | 0402
5 | C_ACCEL_1 | C_0402_1005Metric | 1 | 10nF | CL05B103KB5NNNC | Samsung Electro-Mechanics | 0402
6 | C_ACCEL_2 | C_0402_1005Metric | 1 | 100pF | 0402CG101J500NT | FH (Guangdong Fenghua Advanced Tech) | 0402
7 | C_ACCEL_3 | C_0402_1005Metric | 1 | 2.2nF | CL05B222KB5NNNC | Samsung Electro-Mechanics | 0402
8 | C_BAT1, C_BUCK_IN1, C_OLED_1, C_SYS_1, C_VIN_1 | C_0805_2012Metric | 5 | 10µF | CL21A106KAYNNNE | Samsung Electro-Mechanics | 0805
9 | C_BUCK_OUT1 | C_0805_2012Metric | 1 | 22µF | CL21A226MAQNNNE | Samsung Electro-Mechanics | 0805
10 | C_XBEE_VCC2 | C_0603_1608Metric | 1 | 1µF | CL10A105KB8NNNC | Samsung Electro-Mechanics | 0603
11 | C_XBEE_VCC3 | C_0402_1005Metric | 1 | 47pF | 0402CG470J500NT | FH (Guangdong Fenghua Advanced Tech) | 0402
12 | D_INV_ISO1 | SOT-323_SC-70 | 1 | BAT54W-7-F | Diodes Incorporated | SOT-323 (SC-70)
13 | D_OR1, D_OR2 | D_SOD-123 | 2 | 1N4148W | ST(Semtech) | SOD-123
14 | D_RGB1 | SK6812MINI-E-012 | 1 | SK6812MINI-E-012 | SK6812MINI-E | OPSCO Optoelectronics | SMD 3.2x2.8mm
15 | D_VBUS_TVS1 | D_SOD-323 | 1 | TPPESD5V0S1BA | TECH PUBLIC | SOD-323
16 | J_USB1 | USB_C_Receptacle_HRO_TYPE-C-31-M-12 | 1 | USB-C | TYPE-C-31-M-12 | Hroparts Elec | USB-C receptacle
17 | L_BUCK1 | L_Bourns-SRN4018 | 1 | 2.2µH | SRN4018-2R2M | Bourns | 4.0x4.0mm SMD
18 | Q_INV1 | SOT-23 | 1 | MMBT3904(RANGE:100-300) | Jiangsu Changjing Electronics Technology Co Ltd | SOT-23
19 | Q_LATCH1 | SOT-23 | 1 | AO3400A | Alpha & Omega Semicon | SOT-23
20 | Q_PWR1 | SOT-23 | 1 | AO3401A | Alpha & Omega Semicon | SOT-23
21 | R_BOOT_PU1, R_EN_PU1, R_STAT1, R_STAT2, R_TS1, R_XBEE_ATTN_PU1, R_XBEE_RST1 | R_0402_1005Metric | 7 | 10kΩ | 0402WGF1002TCE | UNI-ROYAL(Uniroyal Elec) | 0402
22 | R_BTN_PU1, R_GATE1, R_INV_BASE1, R_INV_PU1, R_PWR_EN_PD1, R_VSYS2 | R_0402_1005Metric | 6 | 100kΩ | 0402WGF1003TCE | UNI-ROYAL(Uniroyal Elec) | 0402
23 | R_CC1, R_CC2 | R_0402_1005Metric | 2 | 5.1kΩ | 0402WGF5101TCE | UNI-ROYAL(Uniroyal Elec) | 0402
24 | R_FB1 | R_0402_1005Metric | 1 | RC0402FR-07255KL | Yageo | 0402
25 | R_FB2 | R_0402_1005Metric | 1 | 56.2kΩ | RC0402FR-0756K2L | Yageo | 0402
26 | R_ISET1 | R_0402_1005Metric | 1 | AC0402FR-07604RL | Yageo | 0402
27 | R_LATCH_G1 | R_0402_1005Metric | 1 | 1MΩ | 0402WGF1004TCE | UNI-ROYAL(Uniroyal Elec) | 0402
28 | R_RGB1 | R_0402_1005Metric | 1 | 0402WGF4700TCE | UNI-ROYAL(Uniroyal Elec) | 0402
29 | R_USB_DM1, R_USB_DP1 | R_0402_1005Metric | 2 | RC0402FR-0727RL | Yageo | 0402
30 | R_VSET1 | R_0402_1005Metric | 1 | RC0402FR-0718KL | Yageo | 0402
31 | R_VSYS1 | R_0402_1005Metric | 1 | 200kΩ | 0402WGF2003TCE | UNI-ROYAL(Uniroyal Elec) | 0402
32 | R_XBEE_RC1 | R_0402_1005Metric | 1 | 0402WGF1000TCE | UNI-ROYAL(Uniroyal Elec) | 0402
33 | SW_BOOT1 | SW_SPST_EVQP2_ShortPushTravel_H2.1mm | 1 | Panasonic_EVQP2 | EVQP2T02M | Panasonic | SMD tactile 2.1mm
34 | SW_MACRO1, SW_MACRO2, SW_MACRO3, SW_MACRO4, SW_MACRO5, SW_MACRO6 | SW_Push_1TS009xxxx-xxxx-xxxx_6x6x5mm | 6 | 6x6x5mm SMD Tactile | 1TS009A-1800-5000-CT | Hongyuan Precision | SMD tactile 6x6x5mm
35 | SW_PWR1, SW_THR_DN1, SW_THR_UP1, SW_TRIG_DIG1, SW_VOL_DN1, SW_VOL_UP1 | SW_Push_1P1T-MP_NO_Horizontal_Alps_SKRTLAE010 | 6 | SKRTLAE010 | Alps Alpine | SMD tactile horizontal
36 | U_ACCEL1 | QMA6100P | 1 | QMA6100P | QST | LGA-12 2x2mm
37 | U_BUCK1 | SOT-23-5 | 1 | TLV62569DBVR | Texas Instruments | SOT-23-5
38 | U_CHG1 | IC_BQ25185DLHR | 1 | BQ25185DLHR | Texas Instruments | WSON-10 2.2x2.0mm
39 | U_MCU1 | ESP32-S3-WROOM-1 | 1 | ESP32-S3-WROOM-1-N8 | Espressif Systems | SMD module 18x25.5mm
40 | U_OLED1 | JST_SH_SM04B-SRSS-TB_1x04-1MP_P1.00mm_Horizontal | 1 | JST-SH_4Pin_OLED | SM04B-SRSS-TB(LF)(SN) | JST | SMD horizontal 1.00mm 4-pin

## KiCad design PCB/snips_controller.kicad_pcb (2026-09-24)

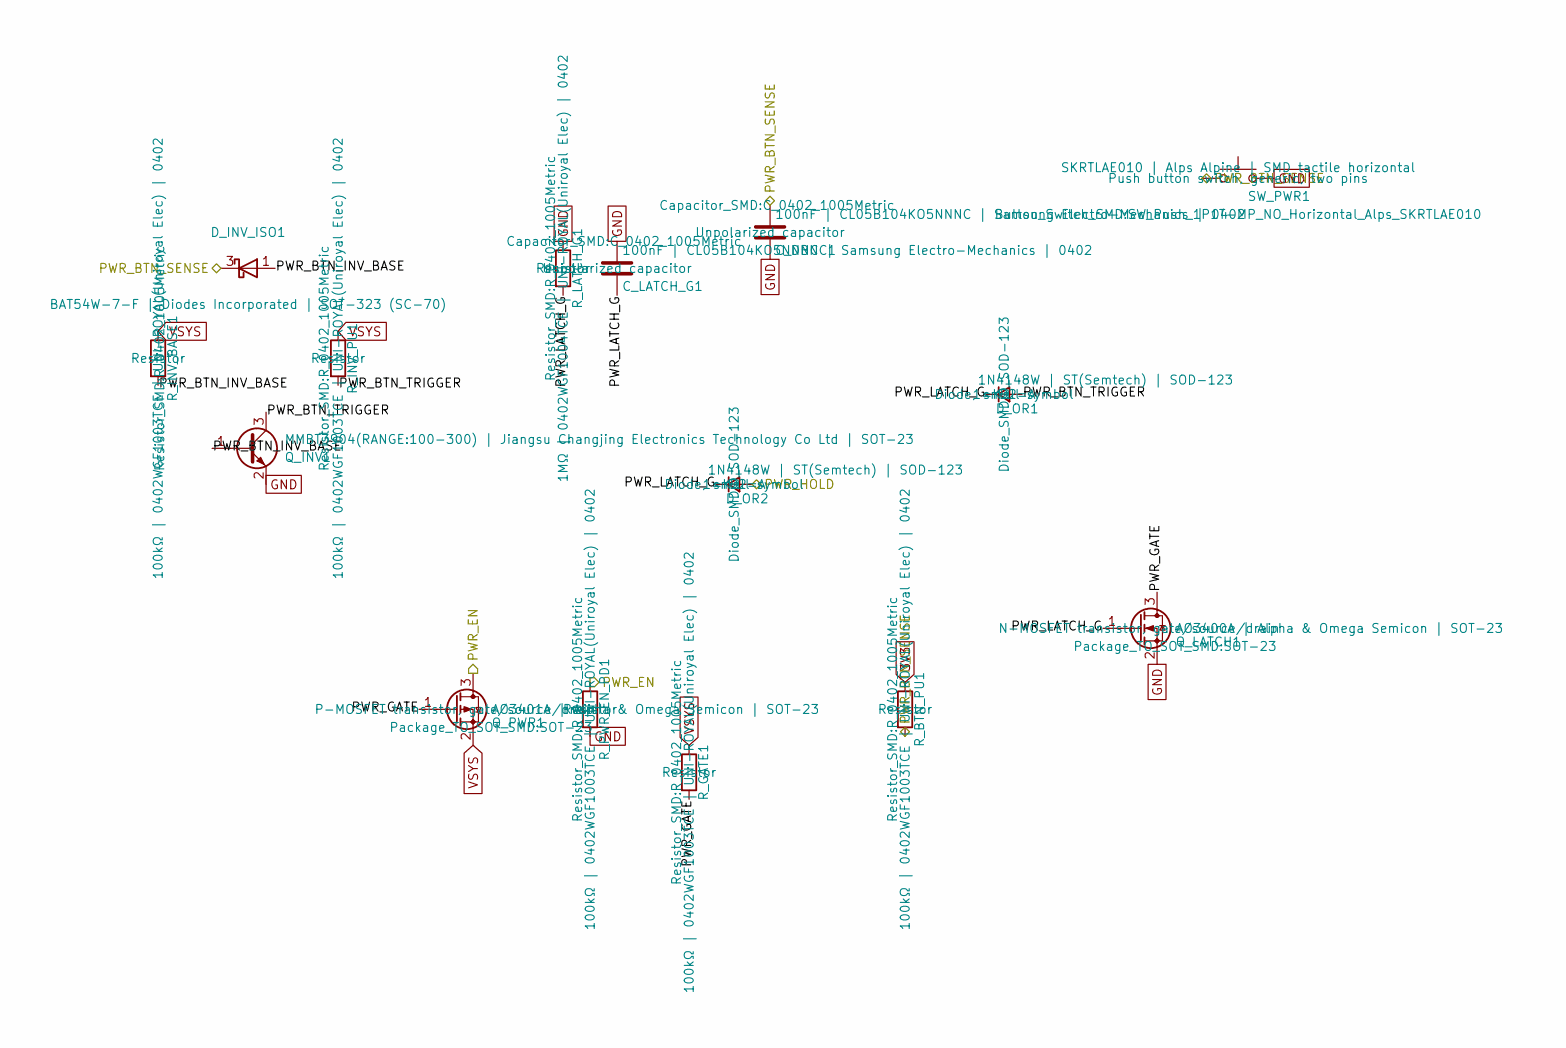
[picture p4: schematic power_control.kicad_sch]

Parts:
C_DBNC1: 100nF | CL05B104KO5NNNC | Samsung Electro-Mechani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; C_0402_1005Metric; Manufacturer_Part_Number CL05B104KO5NNNC; LCSC C1525
C_LATCH_G1: 100nF | CL05B104KO5NNNC | Samsung Electro-Mechani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; C_0402_1005Metric; Manufacturer_Part_Number CL05B104KO5NNNC; LCSC C1525
D_INV_ISO1: BAT54W-7-F | Diodes Incorporated | SOT-323 (SC-70); SOT-323_SC-70; Manufacturer_Part_Number BAT54W-7-F; LCSC C134417
D_OR1, D_OR2: 1N4148W | ST(Semtech) | SOD-123; D_SOD-123; Manufacturer_Part_Number 1N4148W; LCSC C81598
Q_INV1: MMBT3904(RANGE:100-300) | Jiangsu Changjing Elect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; SOT-23; Manufacturer_Part_Number MMBT3904(RANGE:100-300); LCSC C20526
Q_LATCH1: AO3400A | Alpha & Omega Semicon | SOT-23; SOT-23; Manufacturer_Part_Number AO3400A; LCSC C20917
Q_PWR1: AO3401A | Alpha & Omega Semicon | SOT-23; SOT-23; Manufacturer_Part_Number AO3401A; LCSC C15127
R_BTN_PU1: 100kΩ | 0402WGF1003TCE | UNI-ROYAL(Uniroyal Elec)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; R_0402_1005Metric; Manufacturer_Part_Number 0402WGF1003TCE; LCSC C25741
R_GATE1: 100kΩ | 0402WGF1003TCE | UNI-ROYAL(Uniroyal Elec)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; R_0402_1005Metric; Manufacturer_Part_Number 0402WGF1003TCE; LCSC C25741
R_INV_BASE1: 100kΩ | 0402WGF1003TCE | UNI-ROYAL(Uniroyal Elec)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; R_0402_1005Metric; Manufacturer_Part_Number 0402WGF1003TCE; LCSC C25741
R_INV_PU1: 100kΩ | 0402WGF1003TCE | UNI-ROYAL(Uniroyal Elec)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; R_0402_1005Metric; Manufacturer_Part_Number 0402WGF1003TCE; LCSC C25741
R_LATCH_G1: 1MΩ | 0402WGF1004TCE | UNI-ROYAL(Uniroyal Elec) |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; R_0402_1005Metric; Manufacturer_Part_Number 0402WGF1004TCE; LCSC C26083
R_PWR_EN_PD1: 100kΩ | 0402WGF1003TCE | UNI-ROYAL(Uniroyal Elec)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; R_0402_1005Metric; Manufacturer_Part_Number 0402WGF1003TCE; LCSC C25741
SW_PWR1: SKRTLAE010 | Alps Alpine | SMD tactile horizontal; SW_Push_1P1T-MP_NO_Horizontal_Alps_SKRTLAE010; Manufacturer_Part_Number SKRTLAE010; LCSC C110293

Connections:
3V3: R_BTN_PU1.1; also elsewhere on the board
/MCU_Core/PWR_BTN_SENSE: C_DBNC1.1, D_INV_ISO1.3 (K), R_BTN_PU1.2, SW_PWR1.1; also elsewhere on the board
/MCU_Core/PWR_HOLD: D_OR2.2 (A); also elsewhere on the board
/Power_Buck/PWR_EN: Q_PWR1.3 (D), R_PWR_EN_PD1.1; also elsewhere on the board
/Power_Control/PWR_BTN_INV_BASE: D_INV_ISO1.1 (A), Q_INV1.1 (B), R_INV_BASE1.2
/Power_Control/PWR_BTN_TRIGGER: D_OR1.2 (A), Q_INV1.3 (C), R_INV_PU1.2
/Power_Control/PWR_GATE: Q_LATCH1.3 (D), Q_PWR1.1 (G), R_GATE1.2
/Power_Control/PWR_LATCH_G: C_LATCH_G1.2, D_OR1.1 (K), D_OR2.1 (K), Q_LATCH1.1 (G), R_LATCH_G1.2
GND: C_DBNC1.2, C_LATCH_G1.1, Q_INV1.2 (E), Q_LATCH1.2 (S), R_LATCH_G1.1, R_PWR_EN_PD1.2, SW_PWR1.2; also elsewhere on the board
VSYS: Q_PWR1.2 (S), R_GATE1.1, R_INV_BASE1.1, R_INV_PU1.1; also elsewhere on the board

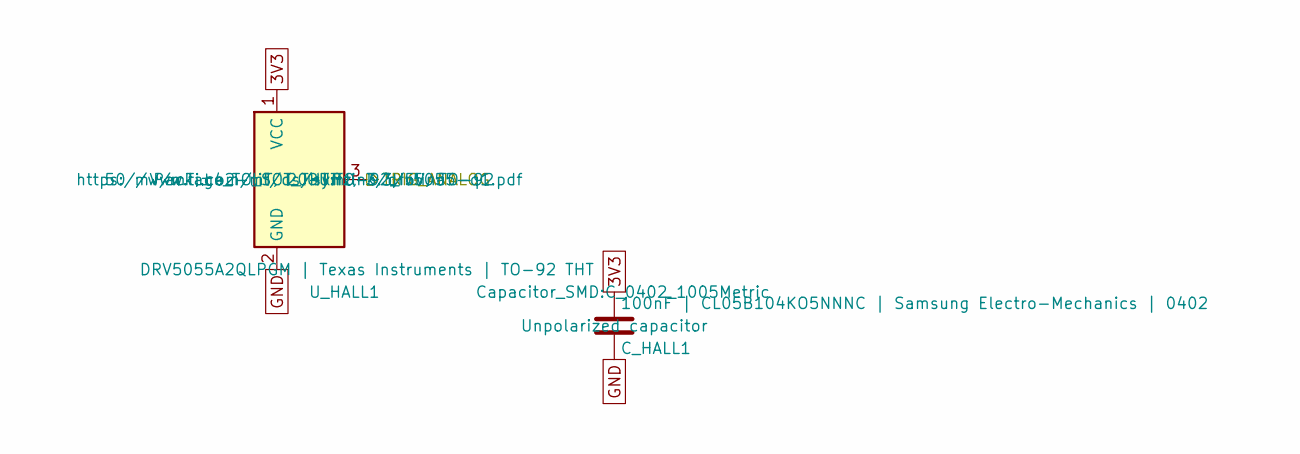
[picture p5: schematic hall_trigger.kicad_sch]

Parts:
C_HALL1: 100nF | CL05B104KO5NNNC | Samsung Electro-Mechani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; C_0402_1005Metric; Manufacturer_Part_Number CL05B104KO5NNNC; LCSC C1525
U_HALL1: DRV5055A2QLPGM | Texas Instruments | TO-92 THT; TO-92_Inline; Manufacturer_Part_Number DRV5055A2QLPGM

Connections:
3V3: C_HALL1.1, U_HALL1.1 (VCC); also elsewhere on the board
/Hall_Trigger/TRIG_ANALOG: U_HALL1.3 (OUT); also elsewhere on the board
GND: C_HALL1.2, U_HALL1.2 (GND); also elsewhere on the board

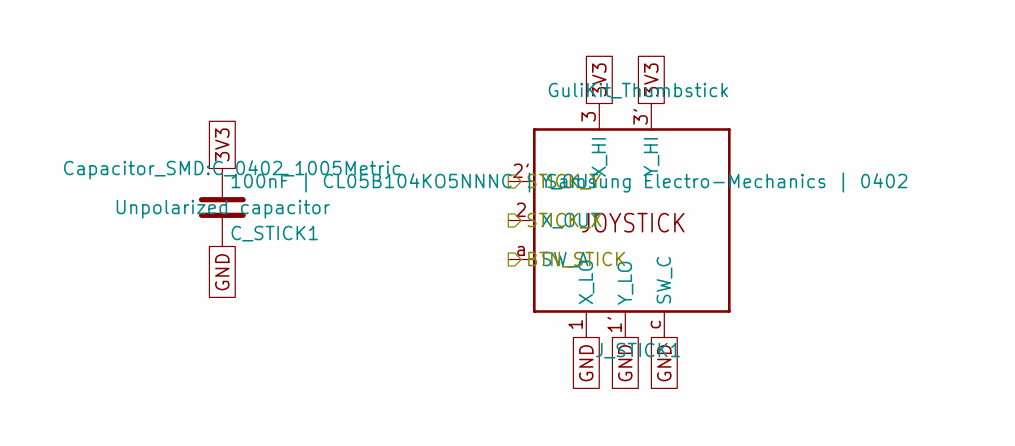
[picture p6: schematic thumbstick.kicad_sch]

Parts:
C_STICK1: 100nF | CL05B104KO5NNNC | Samsung Electro-Mechani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; C_0402_1005Metric; Manufacturer_Part_Number CL05B104KO5NNNC; LCSC C1525
J_STICK1: GuliKit_Thumbstick; GuliKit_HallStick

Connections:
3V3: C_STICK1.1, J_STICK1.3 (X_HI), J_STICK1.3' (Y_HI); also elsewhere on the board
/MCU_Core/BTN_STICK: J_STICK1.a (SW_A); also elsewhere on the board
/MCU_Core/STICK_X: J_STICK1.2 (X_OUT); also elsewhere on the board
/MCU_Core/STICK_Y: J_STICK1.2' (Y_OUT); also elsewhere on the board
GND: C_STICK1.2, J_STICK1.1 (X_LO), J_STICK1.1' (Y_LO), J_STICK1.c (SW_C); also elsewhere on the board

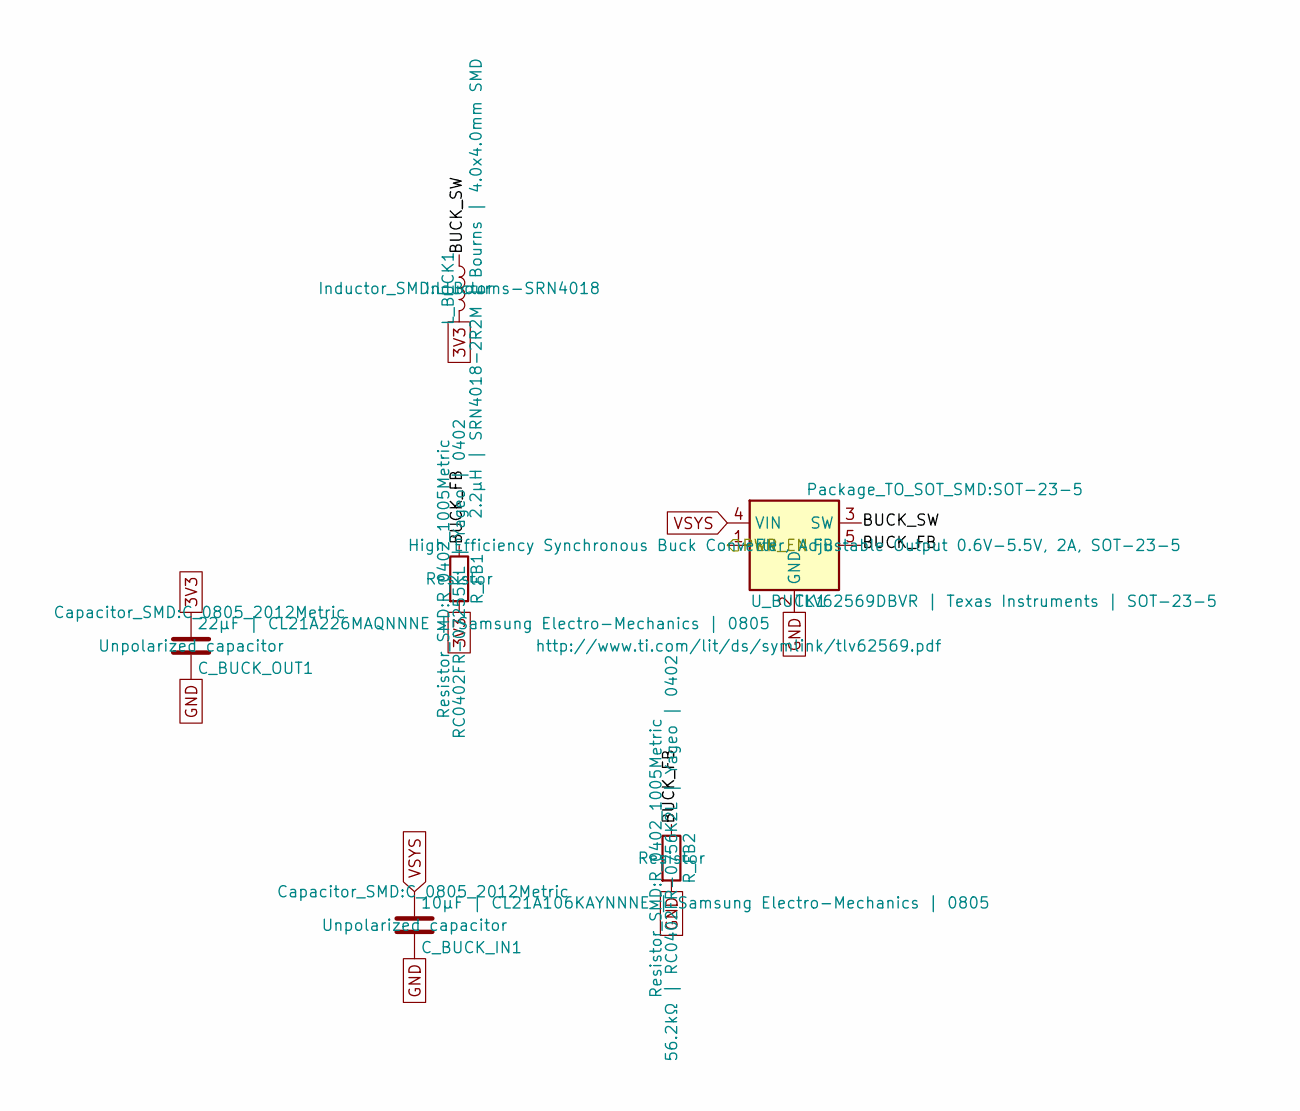
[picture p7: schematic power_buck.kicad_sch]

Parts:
C_BUCK_IN1: 10µF | CL21A106KAYNNNE | Samsung Electro-Mechanic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; C_0805_2012Metric; Manufacturer_Part_Number CL21A106KAYNNNE; LCSC C15850
C_BUCK_OUT1: 22µF | CL21A226MAQNNNE | Samsung Electro-Mechanic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; C_0805_2012Metric; Manufacturer_Part_Number CL21A226MAQNNNE; LCSC C45783
L_BUCK1: 2.2µH | SRN4018-2R2M | Bourns | 4.0x4.0mm SMD; L_Bourns-SRN4018; Manufacturer_Part_Number SRN4018-2R2M; LCSC C913207
R_FB1: RC0402FR-07255KL | Yageo | 0402; R_0402_1005Metric; Manufacturer_Part_Number RC0402FR-07255KL; LCSC C327361
R_FB2: 56.2kΩ | RC0402FR-0756K2L | Yageo | 0402; R_0402_1005Metric; Manufacturer_Part_Number RC0402FR-0756K2L; LCSC C183355
U_BUCK1: TLV62569DBVR | Texas Instruments | SOT-23-5; SOT-23-5; Manufacturer_Part_Number TLV62569DBVR; LCSC C141836

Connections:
3V3: C_BUCK_OUT1.1, L_BUCK1.2, R_FB1.2; also elsewhere on the board
/Power_Buck/BUCK_FB: R_FB1.1, R_FB2.1, U_BUCK1.5 (FB)
/Power_Buck/BUCK_SW: L_BUCK1.1, U_BUCK1.3 (SW)
/Power_Buck/PWR_EN: U_BUCK1.1 (EN); also elsewhere on the board
GND: C_BUCK_IN1.2, C_BUCK_OUT1.2, R_FB2.2, U_BUCK1.2 (GND); also elsewhere on the board
VSYS: C_BUCK_IN1.1, U_BUCK1.4 (VIN); also elsewhere on the board

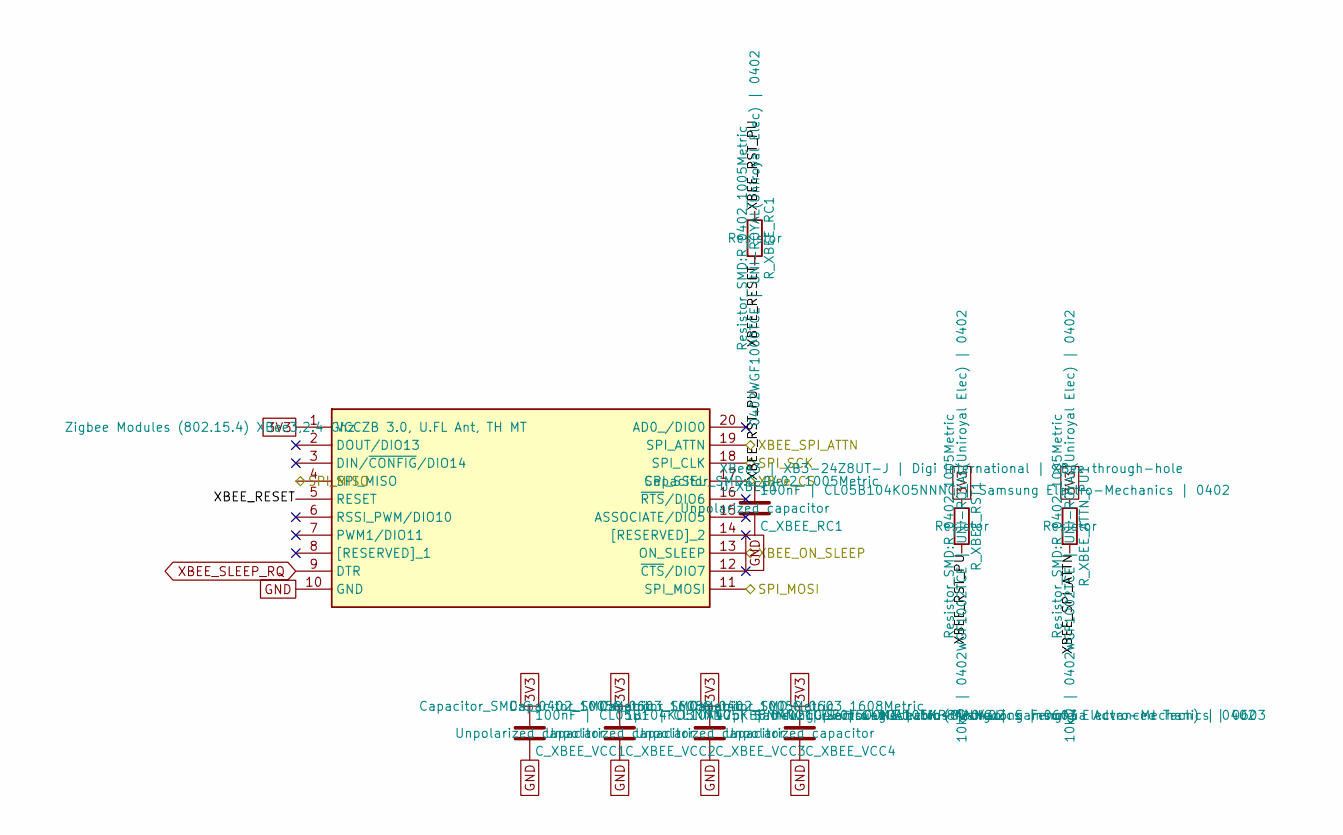
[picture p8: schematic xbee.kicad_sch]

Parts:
C_XBEE_RC1: 100nF | CL05B104KO5NNNC | Samsung Electro-Mechani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; C_0402_1005Metric; Manufacturer_Part_Number CL05B104KO5NNNC; LCSC C1525
C_XBEE_VCC1: 100nF | CL05B104KO5NNNC | Samsung Electro-Mechani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; C_0402_1005Metric; Manufacturer_Part_Number CL05B104KO5NNNC; LCSC C1525
C_XBEE_VCC2: 1µF | CL10A105KB8NNNC | Samsung Electro-Mechanics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; C_0603_1608Metric; Manufacturer_Part_Number CL10A105KB8NNNC; LCSC C15849
C_XBEE_VCC3: 47pF | 0402CG470J500NT | FH (Guangdong Fenghua Ad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; C_0402_1005Metric; Manufacturer_Part_Number 0402CG470J500NT; LCSC C1567
C_XBEE_VCC4: 10µF | CL10A106KP8NNNC | Samsung Electro-Mechanic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; C_0603_1608Metric; Manufacturer_Part_Number CL10A106KP8NNNC; LCSC C19702
R_XBEE_ATTN_PU1: 10kΩ | 0402WGF1002TCE | UNI-ROYAL(Uniroyal Elec) 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; R_0402_1005Metric; Manufacturer_Part_Number 0402WGF1002TCE; LCSC C25744
R_XBEE_RC1: 0402WGF1000TCE | UNI-ROYAL(Uniroyal Elec) | 0402; R_0402_1005Metric; Manufacturer_Part_Number 0402WGF1000TCE; LCSC C25076
R_XBEE_RST1: 10kΩ | 0402WGF1002TCE | UNI-ROYAL(Uniroyal Elec) 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; R_0402_1005Metric; Manufacturer_Part_Number 0402WGF1002TCE; LCSC C25744
U_XBEE1: XBee3 | XB3-24Z8UT-J | Digi International | XBee 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; XB324Z8UTJ; Mouser Part Number 888-XB3-24Z8UT-J

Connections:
3V3: C_XBEE_VCC1.1, C_XBEE_VCC2.1, C_XBEE_VCC3.1, C_XBEE_VCC4.1, R_XBEE_ATTN_PU1.1, R_XBEE_RST1.1, U_XBEE1.1 (VCC); also elsewhere on the board
/MCU_Core/SPI_MISO: U_XBEE1.4 (SPI_MISO); also elsewhere on the board
/MCU_Core/SPI_MOSI: U_XBEE1.11 (SPI_MOSI); also elsewhere on the board
/MCU_Core/SPI_SCK: U_XBEE1.18 (SPI_CLK); also elsewhere on the board
/MCU_Core/XBEE_ON_SLEEP: U_XBEE1.13 (ON_SLEEP); also elsewhere on the board
/MCU_Core/XBee_CS: U_XBEE1.17 (SPI_SSEL); also elsewhere on the board
/XBee/XBEE_RESET: R_XBEE_RC1.2, U_XBEE1.5 (RESET)
/XBee/XBEE_RST_PU: C_XBEE_RC1.1, R_XBEE_RC1.1, R_XBEE_RST1.2
/XBee/XBEE_SPI_ATTN: R_XBEE_ATTN_PU1.2, U_XBEE1.19 (SPI_ATTN); also elsewhere on the board
GND: C_XBEE_RC1.2, C_XBEE_VCC1.2, C_XBEE_VCC2.2, C_XBEE_VCC3.2, C_XBEE_VCC4.2, U_XBEE1.10 (GND); also elsewhere on the board
XBEE_SLEEP_RQ: U_XBEE1.9 (DTR); also elsewhere on the board

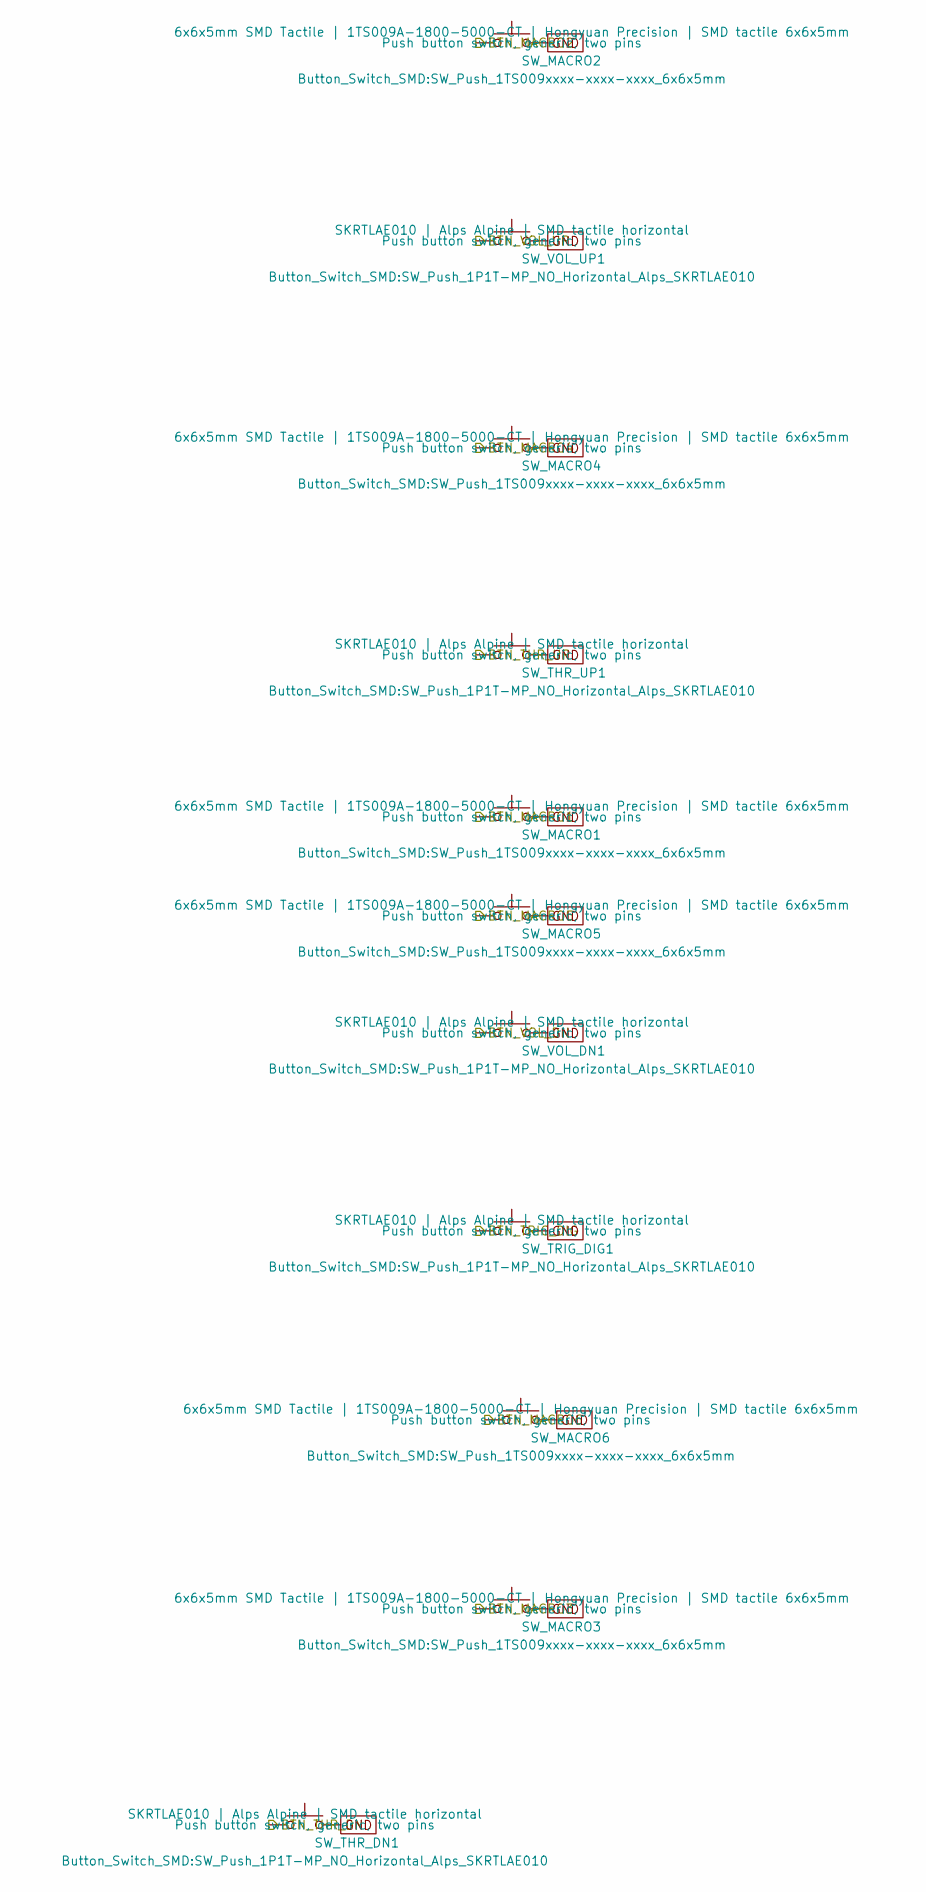
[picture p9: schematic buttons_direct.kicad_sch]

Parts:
SW_MACRO1, SW_MACRO2, SW_MACRO3, SW_MACRO4, SW_MACRO5, SW_MACRO6: 6x6x5mm SMD Tactile | 1TS009A-1800-5000-CT | Hong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; SW_Push_1TS009xxxx-xxxx-xxxx_6x6x5mm; Manufacturer_Part_Number 1TS009A-1800-5000-CT; LCSC C319409
SW_THR_DN1: SKRTLAE010 | Alps Alpine | SMD tactile horizontal; SW_Push_1P1T-MP_NO_Horizontal_Alps_SKRTLAE010; Manufacturer_Part_Number SKRTLAE010; LCSC C110293
SW_THR_UP1: SKRTLAE010 | Alps Alpine | SMD tactile horizontal; SW_Push_1P1T-MP_NO_Horizontal_Alps_SKRTLAE010; Manufacturer_Part_Number SKRTLAE010; LCSC C110293
SW_TRIG_DIG1: SKRTLAE010 | Alps Alpine | SMD tactile horizontal; SW_Push_1P1T-MP_NO_Horizontal_Alps_SKRTLAE010; Manufacturer_Part_Number SKRTLAE010; LCSC C110293
SW_VOL_DN1: SKRTLAE010 | Alps Alpine | SMD tactile horizontal; SW_Push_1P1T-MP_NO_Horizontal_Alps_SKRTLAE010; Manufacturer_Part_Number SKRTLAE010; LCSC C110293
SW_VOL_UP1: SKRTLAE010 | Alps Alpine | SMD tactile horizontal; SW_Push_1P1T-MP_NO_Horizontal_Alps_SKRTLAE010; Manufacturer_Part_Number SKRTLAE010; LCSC C110293

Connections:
/Buttons_Direct/BTN_MACRO1: SW_MACRO1.1; also elsewhere on the board
/Buttons_Direct/BTN_MACRO2: SW_MACRO2.1; also elsewhere on the board
/Buttons_Direct/BTN_MACRO3: SW_MACRO3.1; also elsewhere on the board
/Buttons_Direct/BTN_MACRO4: SW_MACRO4.1; also elsewhere on the board
/Buttons_Direct/BTN_MACRO5: SW_MACRO5.1; also elsewhere on the board
/Buttons_Direct/BTN_MACRO6: SW_MACRO6.1; also elsewhere on the board
/Buttons_Direct/BTN_THR_DN: SW_THR_DN1.1; also elsewhere on the board
/Buttons_Direct/BTN_THR_UP: SW_THR_UP1.1; also elsewhere on the board
/Buttons_Direct/BTN_TRIG_DIG: SW_TRIG_DIG1.1; also elsewhere on the board
/Buttons_Direct/BTN_VOL_DN: SW_VOL_DN1.1; also elsewhere on the board
/Buttons_Direct/BTN_VOL_UP: SW_VOL_UP1.1; also elsewhere on the board
GND: SW_MACRO1.2, SW_MACRO2.2, SW_MACRO3.2, SW_MACRO4.2, SW_MACRO5.2, SW_MACRO6.2, SW_THR_DN1.2, SW_THR_UP1.2, SW_TRIG_DIG1.2, SW_VOL_DN1.2, SW_VOL_UP1.2; also elsewhere on the board

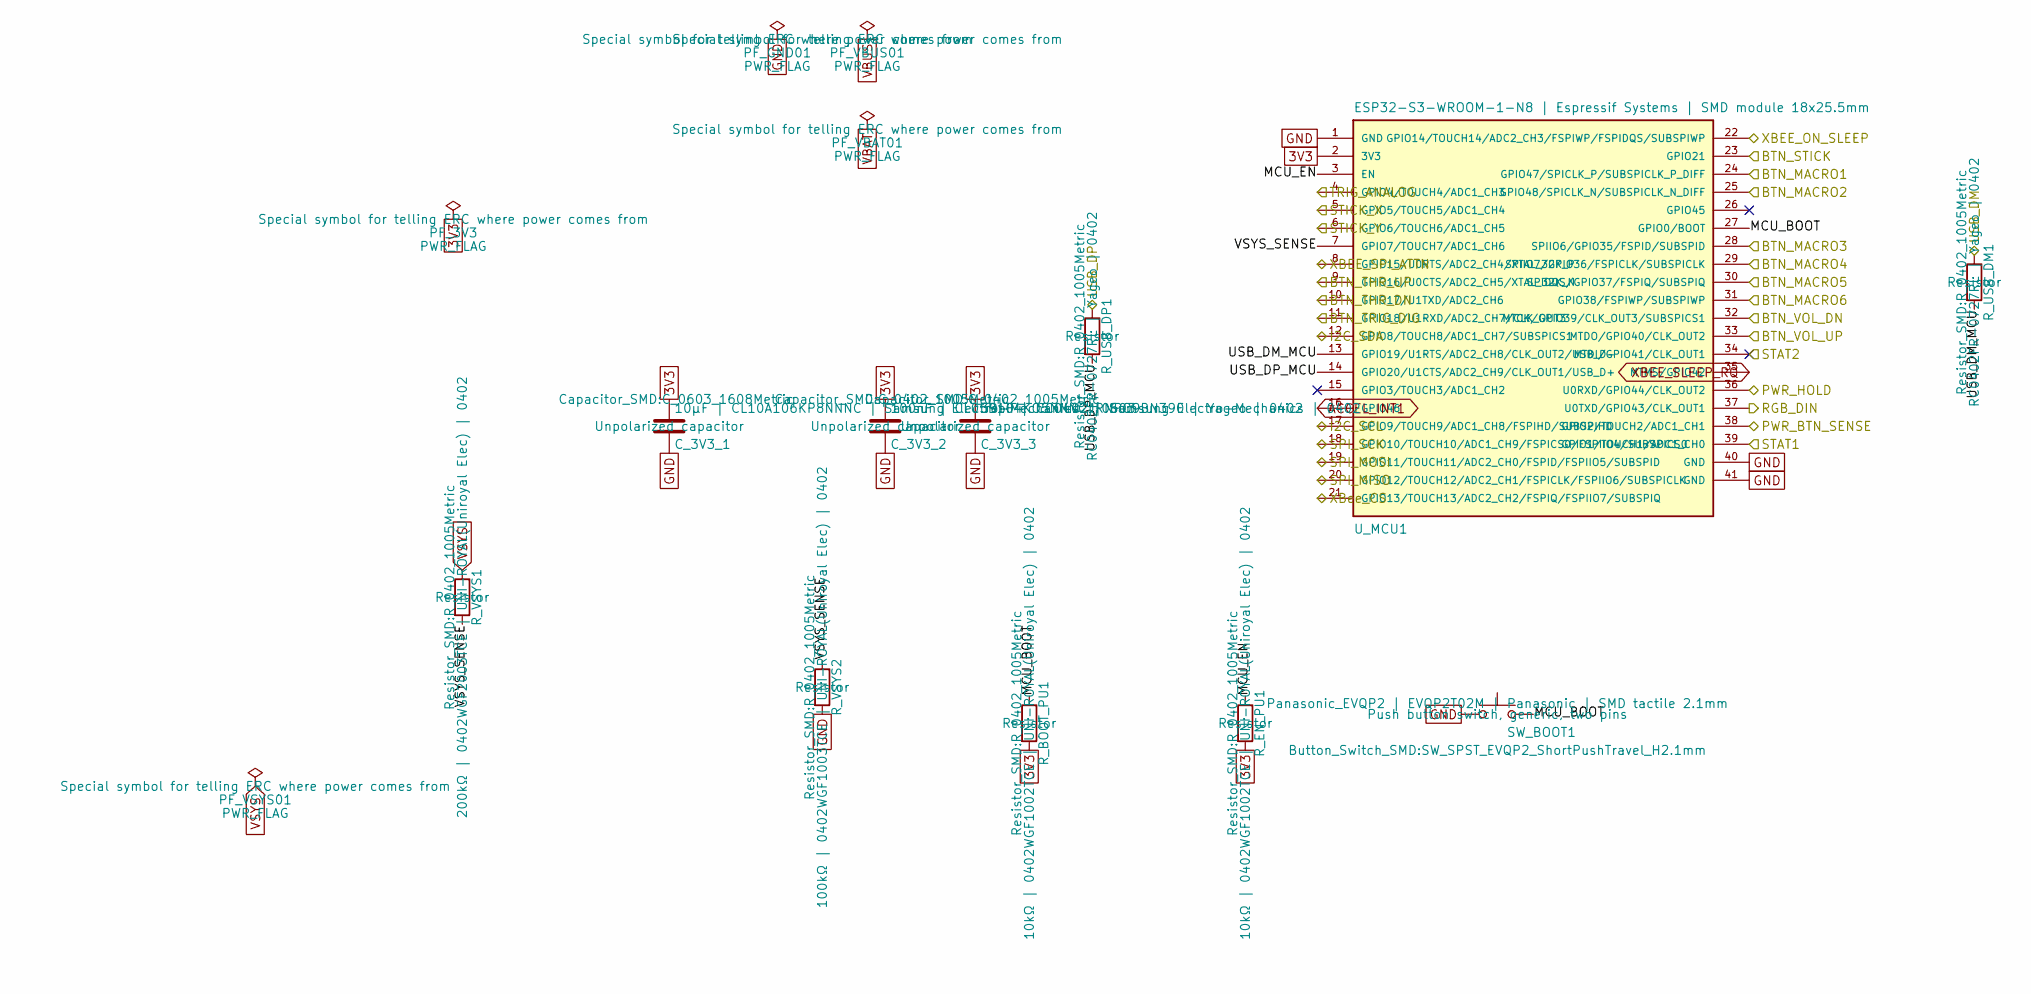
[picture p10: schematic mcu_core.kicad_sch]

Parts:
C_3V3_1: 10µF | CL10A106KP8NNNC | Samsung Electro-Mechanic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; C_0603_1608Metric; Manufacturer_Part_Number CL10A106KP8NNNC; LCSC C19702
C_3V3_2: 100nF | CL05B104KO5NNNC | Samsung Electro-Mechani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; C_0402_1005Metric; Manufacturer_Part_Number CL05B104KO5NNNC; LCSC C1525
C_3V3_3: 39pF | CC0402JRNPO9BN390 | Yageo | 0402; C_0402_1005Metric; Manufacturer_Part_Number CC0402JRNPO9BN390; LCSC C106223
PF_3V3: PWR_FLAG
PF_GND01: PWR_FLAG
PF_VBAT01: PWR_FLAG
PF_VBUS01: PWR_FLAG
PF_VSYS01: PWR_FLAG
R_BOOT_PU1: 10kΩ | 0402WGF1002TCE | UNI-ROYAL(Uniroyal Elec) 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; R_0402_1005Metric; Manufacturer_Part_Number 0402WGF1002TCE; LCSC C25744
R_EN_PU1: 10kΩ | 0402WGF1002TCE | UNI-ROYAL(Uniroyal Elec) 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; R_0402_1005Metric; Manufacturer_Part_Number 0402WGF1002TCE; LCSC C25744
R_USB_DM1: RC0402FR-0727RL | Yageo | 0402; R_0402_1005Metric; Manufacturer_Part_Number RC0402FR-0727RL; LCSC C138021
R_USB_DP1: RC0402FR-0727RL | Yageo | 0402; R_0402_1005Metric; Manufacturer_Part_Number RC0402FR-0727RL; LCSC C138021
R_VSYS1: 200kΩ | 0402WGF2003TCE | UNI-ROYAL(Uniroyal Elec)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; R_0402_1005Metric; Manufacturer_Part_Number 0402WGF2003TCE; LCSC C25764
R_VSYS2: 100kΩ | 0402WGF1003TCE | UNI-ROYAL(Uniroyal Elec)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; R_0402_1005Metric; Manufacturer_Part_Number 0402WGF1003TCE; LCSC C25741
SW_BOOT1: Panasonic_EVQP2 | EVQP2T02M | Panasonic | SMD tac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; SW_SPST_EVQP2_ShortPushTravel_H2.1mm; Manufacturer_Part_Number EVQP2T02M; LCSC C2915174
U_MCU1: ESP32-S3-WROOM-1-N8 | Espressif Systems | SMD mod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; ESP32-S3-WROOM-1; Manufacturer_Part_Number ESP32-S3-WROOM-1-N8; LCSC C2913198

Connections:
3V3: C_3V3_1.1, C_3V3_2.1, C_3V3_3.1, PF_3V3.1, R_BOOT_PU1.2, R_EN_PU1.2, U_MCU1.2 (3V3); also elsewhere on the board
/Accelerometer/I2C_SCL: U_MCU1.17 (GPIO9/TOUCH9/ADC1_CH8/FSPIHD/SUBSPIHD); also elsewhere on the board
/Accelerometer/I2C_SDA: U_MCU1.12 (GPIO8/TOUCH8/ADC1_CH7/SUBSPICS1); also elsewhere on the board
/Buttons_Direct/BTN_MACRO1: U_MCU1.24 (GPIO47/SPICLK_P/SUBSPICLK_P_DIFF); also elsewhere on the board
/Buttons_Direct/BTN_MACRO2: U_MCU1.25 (GPIO48/SPICLK_N/SUBSPICLK_N_DIFF); also elsewhere on the board
/Buttons_Direct/BTN_MACRO3: U_MCU1.28 (SPIIO6/GPIO35/FSPID/SUBSPID); also elsewhere on the board
/Buttons_Direct/BTN_MACRO4: U_MCU1.29 (SPIIO7/GPIO36/FSPICLK/SUBSPICLK); also elsewhere on the board
/Buttons_Direct/BTN_MACRO5: U_MCU1.30 (SPIDQS/GPIO37/FSPIQ/SUBSPIQ); also elsewhere on the board
/Buttons_Direct/BTN_MACRO6: U_MCU1.31 (GPIO38/FSPIWP/SUBSPIWP); also elsewhere on the board
/Buttons_Direct/BTN_THR_DN: U_MCU1.10 (GPIO17/U1TXD/ADC2_CH6); also elsewhere on the board
/Buttons_Direct/BTN_THR_UP: U_MCU1.9 (GPIO16/U0CTS/ADC2_CH5/XTAL_32K_N); also elsewhere on the board
/Buttons_Direct/BTN_TRIG_DIG: U_MCU1.11 (GPIO18/U1RXD/ADC2_CH7/CLK_OUT3); also elsewhere on the board
/Buttons_Direct/BTN_VOL_DN: U_MCU1.32 (MTCK/GPIO39/CLK_OUT3/SUBSPICS1); also elsewhere on the board
/Buttons_Direct/BTN_VOL_UP: U_MCU1.33 (MTDO/GPIO40/CLK_OUT2); also elsewhere on the board
/Hall_Trigger/TRIG_ANALOG: U_MCU1.4 (GPIO4/TOUCH4/ADC1_CH3); also elsewhere on the board
/MCU_Core/BTN_STICK: U_MCU1.23 (GPIO21); also elsewhere on the board
/MCU_Core/MCU_BOOT: R_BOOT_PU1.1, SW_BOOT1.2, U_MCU1.27 (GPIO0/BOOT)
/MCU_Core/MCU_EN: R_EN_PU1.1, U_MCU1.3 (EN)
/MCU_Core/PWR_BTN_SENSE: U_MCU1.38 (GPIO2/TOUCH2/ADC1_CH1); also elsewhere on the board
/MCU_Core/PWR_HOLD: U_MCU1.36 (U0RXD/GPIO44/CLK_OUT2); also elsewhere on the board
/MCU_Core/RGB_DIN: U_MCU1.37 (U0TXD/GPIO43/CLK_OUT1); also elsewhere on the board
/MCU_Core/SPI_MISO: U_MCU1.20 (GPIO12/TOUCH12/ADC2_CH1/FSPICLK/FSPIIO6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); also elsewhere on the board
/MCU_Core/SPI_MOSI: U_MCU1.19 (GPIO11/TOUCH11/ADC2_CH0/FSPID/FSPIIO5/S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); also elsewhere on the board
/MCU_Core/SPI_SCK: U_MCU1.18 (GPIO10/TOUCH10/ADC1_CH9/FSPICS0/FSPIIO4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); also elsewhere on the board
/MCU_Core/STAT1: U_MCU1.39 (GPIO1/TOUCH1/ADC1_CH0); also elsewhere on the board
/MCU_Core/STAT2: U_MCU1.34 (MTDI/GPIO41/CLK_OUT1); also elsewhere on the board
/MCU_Core/STICK_X: U_MCU1.5 (GPIO5/TOUCH5/ADC1_CH4); also elsewhere on the board
/MCU_Core/STICK_Y: U_MCU1.6 (GPIO6/TOUCH6/ADC1_CH5); also elsewhere on the board
/MCU_Core/USB_DM: R_USB_DM1.1; also elsewhere on the board
/MCU_Core/USB_DM_MCU: R_USB_DM1.2, U_MCU1.13 (GPIO19/U1RTS/ADC2_CH8/CLK_OUT2/USB_D-)
/MCU_Core/USB_DP: R_USB_DP1.1; also elsewhere on the board
/MCU_Core/USB_DP_MCU: R_USB_DP1.2, U_MCU1.14 (GPIO20/U1CTS/ADC2_CH9/CLK_OUT1/USB_D+)
/MCU_Core/VSYS_SENSE: R_VSYS1.2, R_VSYS2.1, U_MCU1.7 (GPIO7/TOUCH7/ADC1_CH6)
/MCU_Core/XBEE_ON_SLEEP: U_MCU1.22 (GPIO14/TOUCH14/ADC2_CH3/FSPIWP/FSPIDQS/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); also elsewhere on the board
/MCU_Core/XBee_CS: U_MCU1.21 (GPIO13/TOUCH13/ADC2_CH2/FSPIQ/FSPIIO7/S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); also elsewhere on the board
/XBee/XBEE_SPI_ATTN: U_MCU1.8 (GPIO15/U0RTS/ADC2_CH4/XTAL_32K_P); also elsewhere on the board
ACCEL_INT1: U_MCU1.16 (GPIO46); also elsewhere on the board
GND: C_3V3_1.2, C_3V3_2.2, C_3V3_3.2, PF_GND01.1, R_VSYS2.2, SW_BOOT1.1, U_MCU1.1 (GND), U_MCU1.40 (GND), U_MCU1.41 (GND); also elsewhere on the board
VSYS: PF_VSYS01.1, R_VSYS1.1; also elsewhere on the board
XBEE_SLEEP_RQ: U_MCU1.35 (MTMS/GPIO42); also elsewhere on the board

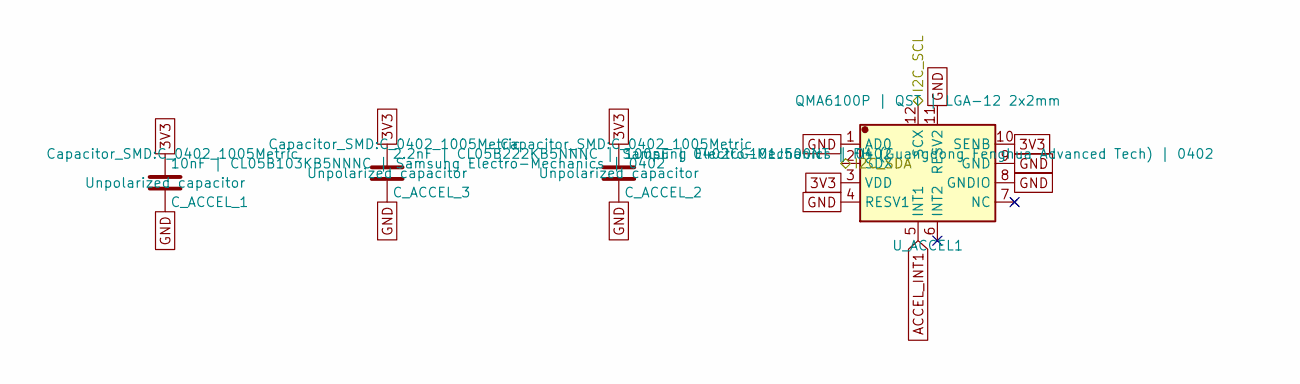
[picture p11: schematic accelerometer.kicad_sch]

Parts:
C_ACCEL_1: 10nF | CL05B103KB5NNNC | Samsung Electro-Mechanic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; C_0402_1005Metric; Manufacturer_Part_Number CL05B103KB5NNNC; LCSC C15195
C_ACCEL_2: 100pF | 0402CG101J500NT | FH (Guangdong Fenghua A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; C_0402_1005Metric; Manufacturer_Part_Number 0402CG101J500NT; LCSC C1546
C_ACCEL_3: 2.2nF | CL05B222KB5NNNC | Samsung Electro-Mechani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; C_0402_1005Metric; Manufacturer_Part_Number CL05B222KB5NNNC; LCSC C84703
U_ACCEL1: QMA6100P | QST | LGA-12 2x2mm; QMA6100P; Manufacturer_Part_Number QMA6100P; LCSC C2887190

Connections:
3V3: C_ACCEL_1.1, C_ACCEL_2.1, C_ACCEL_3.1, U_ACCEL1.3 (VDD), U_ACCEL1.10 (SENB); also elsewhere on the board
/Accelerometer/I2C_SCL: U_ACCEL1.12 (SCX); also elsewhere on the board
/Accelerometer/I2C_SDA: U_ACCEL1.2 (SDX); also elsewhere on the board
ACCEL_INT1: U_ACCEL1.5 (INT1); also elsewhere on the board
GND: C_ACCEL_1.2, C_ACCEL_2.2, C_ACCEL_3.2, U_ACCEL1.1 (AD0), U_ACCEL1.4 (RESV1), U_ACCEL1.8 (GNDIO), U_ACCEL1.9 (GND), U_ACCEL1.11 (RESV2); also elsewhere on the board

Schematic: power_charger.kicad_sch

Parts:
C_BAT1: 10µF | CL21A106KAYNNNE | Samsung Electro-Mechanic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; C_0805_2012Metric; Manufacturer_Part_Number CL21A106KAYNNNE; LCSC C15850
C_SYS_1: 10µF | CL21A106KAYNNNE | Samsung Electro-Mechanic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; C_0805_2012Metric; Manufacturer_Part_Number CL21A106KAYNNNE; LCSC C15850
C_SYS_2: 100nF | CL05B104KO5NNNC | Samsung Electro-Mechani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; C_0402_1005Metric; Manufacturer_Part_Number CL05B104KO5NNNC; LCSC C1525
C_VIN_1: 10µF | CL21A106KAYNNNE | Samsung Electro-Mechanic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; C_0805_2012Metric; Manufacturer_Part_Number CL21A106KAYNNNE; LCSC C15850
C_VIN_2: 100nF | CL05B104KO5NNNC | Samsung Electro-Mechani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; C_0402_1005Metric; Manufacturer_Part_Number CL05B104KO5NNNC; LCSC C1525
R_ISET1: AC0402FR-07604RL | Yageo | 0402; R_0402_1005Metric; Manufacturer_Part_Number AC0402FR-07604RL; LCSC C227167
R_STAT1, R_STAT2: 10kΩ | 0402WGF1002TCE | UNI-ROYAL(Uniroyal Elec) 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; R_0402_1005Metric; Manufacturer_Part_Number 0402WGF1002TCE; LCSC C25744
R_TS1: 10kΩ | 0402WGF1002TCE | UNI-ROYAL(Uniroyal Elec) 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; R_0402_1005Metric; Manufacturer_Part_Number 0402WGF1002TCE; LCSC C25744
R_VSET1: RC0402FR-0718KL | Yageo | 0402; R_0402_1005Metric; Manufacturer_Part_Number RC0402FR-0718KL; LCSC C138044
U_CHG1: BQ25185DLHR | Texas Instruments | WSON-10 2.2x2.0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; IC_BQ25185DLHR; PARTREV OCTOBER 2023; LCSC C19725033

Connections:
3V3: R_STAT1.2, R_STAT2.2; also elsewhere on the board
/MCU_Core/STAT1: R_STAT1.1, U_CHG1.9 (STAT1); also elsewhere on the board
/MCU_Core/STAT2: R_STAT2.1, U_CHG1.3 (STAT2); also elsewhere on the board
/Power_Charger/CHG_ISET: R_ISET1.1, U_CHG1.8 (ISET)
/Power_Charger/CHG_TS: R_TS1.1, U_CHG1.6 (TS/MR)
/Power_Charger/CHG_VSET: R_VSET1.1, U_CHG1.7 (ILIM/VSET)
GND: C_BAT1.2, C_SYS_1.2, C_SYS_2.2, C_VIN_1.2, C_VIN_2.2, R_ISET1.2, R_TS1.2, R_VSET1.2, U_CHG1.4 (~CE), U_CHG1.5 (GND), U_CHG1.11 (THERMAL_PAD); also elsewhere on the board
VBAT: C_BAT1.1, U_CHG1.2 (BAT); also elsewhere on the board
VBUS: C_VIN_1.1, C_VIN_2.1, U_CHG1.10 (IN); also elsewhere on the board
VSYS: C_SYS_1.1, C_SYS_2.1, U_CHG1.1 (SYS); also elsewhere on the board

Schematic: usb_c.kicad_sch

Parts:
D_VBUS_TVS1: TPPESD5V0S1BA | TECH PUBLIC | SOD-323; D_SOD-323; Manufacturer_Part_Number TPPESD5V0S1BA; LCSC C587144
J_USB1: USB-C | TYPE-C-31-M-12 | Hroparts Elec | USB-C re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; USB_C_Receptacle_HRO_TYPE-C-31-M-12; Manufacturer_Part_Number TYPE-C-31-M-12; LCSC C165948
R_CC1, R_CC2: 5.1kΩ | 0402WGF5101TCE | UNI-ROYAL(Uniroyal Elec)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; R_0402_1005Metric; Manufacturer_Part_Number 0402WGF5101TCE; LCSC C25905

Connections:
/MCU_Core/USB_DM: J_USB1.A7 (D-), J_USB1.B7 (D-); also elsewhere on the board
/MCU_Core/USB_DP: J_USB1.A6 (D+), J_USB1.B6 (D+); also elsewhere on the board
/USB_C/USB_CC1: J_USB1.A5 (CC1), R_CC1.1
/USB_C/USB_CC2: J_USB1.B5 (CC2), R_CC2.1
GND: D_VBUS_TVS1.2 (A2), J_USB1.A1 (GND), J_USB1.A12 (GND), J_USB1.B1 (GND), J_USB1.B12 (GND), J_USB1.SH (SHIELD), R_CC1.2, R_CC2.2; also elsewhere on the board
VBUS: D_VBUS_TVS1.1 (A1), J_USB1.A4 (VBUS), J_USB1.A9 (VBUS), J_USB1.B4 (VBUS), J_USB1.B9 (VBUS); also elsewhere on the board

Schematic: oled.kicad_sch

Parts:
C_OLED_1: 10µF | CL21A106KAYNNNE | Samsung Electro-Mechanic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; C_0805_2012Metric; Manufacturer_Part_Number CL21A106KAYNNNE; LCSC C15850
C_OLED_2: 100nF | CL05B104KO5NNNC | Samsung Electro-Mechani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; C_0402_1005Metric; Manufacturer_Part_Number CL05B104KO5NNNC; LCSC C1525
U_OLED1: JST-SH_4Pin_OLED | SM04B-SRSS-TB(LF)(SN) | JST | 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; JST_SH_SM04B-SRSS-TB_1x04-1MP_P1.00mm_Horizontal; Manufacturer_Part_Number SM04B-SRSS-TB(LF)(SN); LCSC C160404

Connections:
3V3: C_OLED_1.1, C_OLED_2.1, U_OLED1.2 (VCC); also elsewhere on the board
/Accelerometer/I2C_SCL: U_OLED1.4 (SCL); also elsewhere on the board
/Accelerometer/I2C_SDA: U_OLED1.3 (SDA); also elsewhere on the board
GND: C_OLED_1.2, C_OLED_2.2, U_OLED1.1 (GND); also elsewhere on the board

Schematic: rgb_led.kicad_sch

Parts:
C_RGB1: 100nF | CL05B104KO5NNNC | Samsung Electro-Mechani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; C_0402_1005Metric; Manufacturer_Part_Number CL05B104KO5NNNC; LCSC C1525
D_RGB1: SK6812MINI-E-012 | SK6812MINI-E | OPSCO Optoelect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; SK6812MINI-E-012; Manufacturer_Part_Number SK6812MINI-E; LCSC C5149201
R_RGB1: 0402WGF4700TCE | UNI-ROYAL(Uniroyal Elec) | 0402; R_0402_1005Metric; Manufacturer_Part_Number 0402WGF4700TCE; LCSC C25117

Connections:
3V3: C_RGB1.1, D_RGB1.3 (VDD); also elsewhere on the board
/MCU_Core/RGB_DIN: R_RGB1.2; also elsewhere on the board
/RGB_LED/RGB_DIN_R: D_RGB1.2 (DIN), R_RGB1.1
GND: C_RGB1.2, D_RGB1.1 (VSS); also elsewhere on the board

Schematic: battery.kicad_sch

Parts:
BT1: PH 2-pin battery RIGHT-ANGLE HORIZONTAL | S2B-PH-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; JST_PH_S2B-PH-K_1x02_P2.00mm_Horizontal; Manufacturer_Part_Number S2B-PH-K(LF)(SN); LCSC C265016

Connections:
GND: BT1.2; also elsewhere on the board
VBAT: BT1.1; also elsewhere on the board

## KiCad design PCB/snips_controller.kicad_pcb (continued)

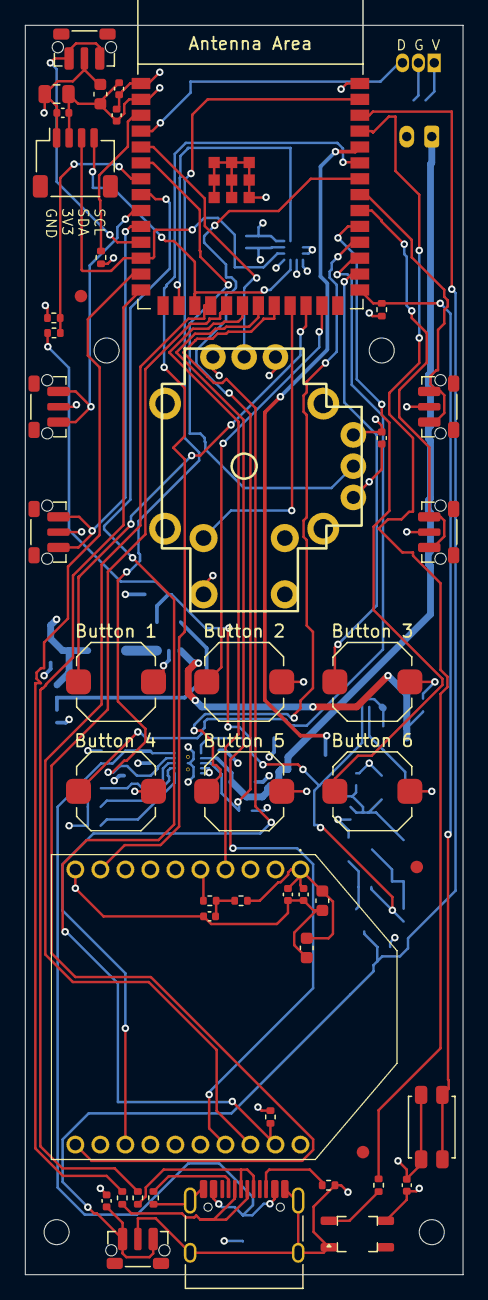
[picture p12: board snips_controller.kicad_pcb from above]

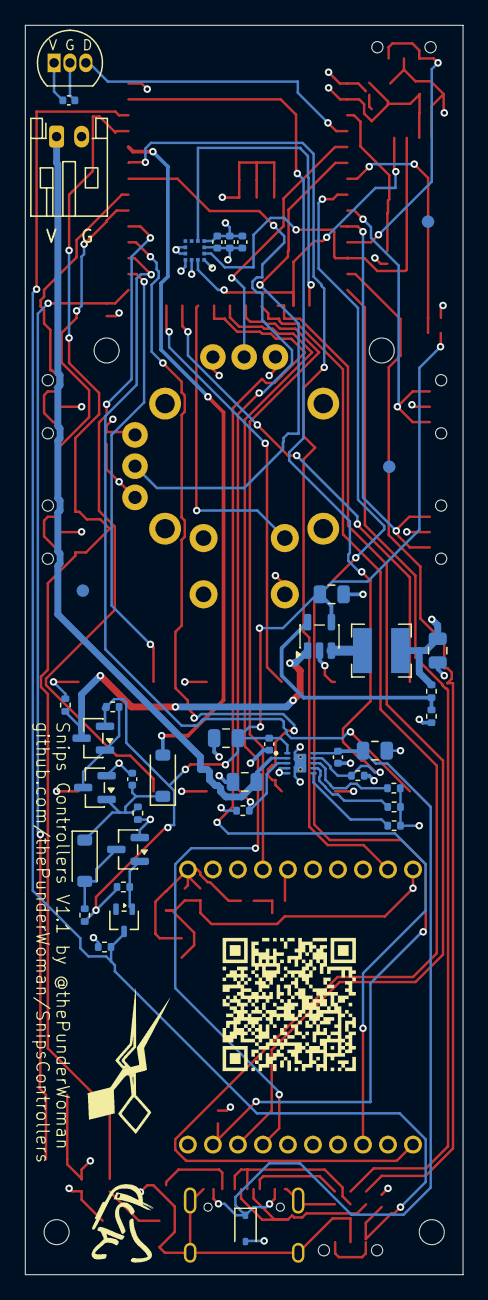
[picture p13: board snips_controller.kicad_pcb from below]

Board: 4 copper layers, 35.0 x 99.9 mm, 86 parts (38 on the bottom side), 57 nets.

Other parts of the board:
MHole: MountingHole_2mm
MHole#2, MHole#3, MHole#4: MountingHole_2mm

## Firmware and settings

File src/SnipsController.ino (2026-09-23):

#include <Arduino.h>
#include <cstring>

#include "accelerometer.h"
#include "battery.h"
#include "buttons.h"
#include "calibration.h"
#include "calibration_store.h"
#include "complication_persistence.h"
#include "complications.h"
#include "droid_persistence.h"
#include "low_battery.h"
#include "menu.h"
#include "oled.h"
#include "packet.h"
#include "pin_assignment.h"
#include "power_config_store.h"
#include "power_latch.h"
#include "power_management.h"
#include "rgb_led.h"
#include "screen.h"
#include "snips_logo_bitmap.h"
#include "status_led.h"
#include "xbee_control.h"

// Pure entry point — wiring only. All real logic lives in dedicated
// subsystem files under src/ + include/; this file just owns real
// peripherals and feeds their raw readings into that logic each tick.

namespace {

PowerOffDetector powerOffDetector;
ButtonPanel buttonPanel;
OledDisplay oledDisplay;
RgbLed rgbLed;
StatusLedController statusLedController;
BatteryMonitor batteryMonitor;
CalibrationData calibrationData;
MenuController menuController;
XbeeControl xbeeControl;
ComplicationRegistry complications;
ComplicationData complicationData;
Accelerometer accelerometer;
PowerManager powerManager;
PowerConfig powerConfig;
PowerTier previousPowerTier = PowerTier::kFull;
LowBatteryMonitor lowBatteryMonitor;
bool wasInLowBatteryCountdown = false;
char deviceSerialLowBuf[9] = {};  // must outlive setup() — see its use below
bool lastReportedPressed[Buttons::kCount] = {};
unsigned long lastTelemetryLogMs = 0;
constexpr unsigned long kTelemetryLogIntervalMs = 1000;
unsigned long lastUplinkSendMs = 0;
constexpr unsigned long kUplinkSendIntervalMs = 50;
unsigned long lastDownlinkMs = 0;  // 0 = never received one
constexpr unsigned long kConnectionTimeoutMs = 5000;
MenuScreen previousMenuScreen = MenuScreen::kInactive;
MainMenuItem previousMainMenuItem = MainMenuItem::kSwitchDroid;

void showBootScreen() {
  ScreenBuffer bootScreen;
  bootScreen.setLine(0, "Snips Controller");
  bootScreen.setLine(1, "OLED OK");
  oledDisplay.render(bootScreen);
}

// The "normal operating" screen, shown whenever the on-device menu is
// closed — smartwatch-style complications, user-assignable via Display
// Config.
void showOperatingScreen() {
  ScreenBuffer screen;
  complications.render(&screen);
  oledDisplay.render(screen);
}

// Applies one power tier's real hardware effects (see power_management.h)
// — called only on transition, not every tick. Driving kXbeeSleepRq high
// on boards where it isn't wired to anything (the first production run —
// see PCB/GPIO_table.md's Accelerometer section) is a harmless no-op, so
// this needs no capability check of its own.
void applyPowerTier(PowerTier tier) {
  const bool oledShouldBeOn =
      tier != PowerTier::kOff && tier != PowerTier::kXbeeAsleep;
  oledDisplay.setPowerOn(oledShouldBeOn);
  oledDisplay.setDimmed(tier == PowerTier::kDim);
  digitalWrite(PinAssignment::kXbeeSleepRq,
              tier == PowerTier::kXbeeAsleep ? HIGH : LOW);

  // Coming back from OLED-off: the panel's GDRAM still has whatever was
  // last drawn before it powered off, which is fine for the operating
  // screen (redrawn every second regardless) but could be a stale menu
  // screen if the user backed out while it was off. Force one fresh
  // redraw on wake to be safe.
  if (oledShouldBeOn) {
    if (menuController.currentScreen() != MenuScreen::kInactive) {
      ScreenBuffer menuScreen;
      renderMenuScreen(menuController, &menuScreen);
      oledDisplay.render(menuScreen);
    } else {
      showOperatingScreen();
    }
  }
}

void copyField(char *dest, size_t destCapacity, const char *src) {
  std::strncpy(dest, src, destCapacity - 1);
  dest[destCapacity - 1] = '\0';
}

// Notifies Amidala this controller is powering off intentionally (so it
// doesn't wait out a stale-connection timeout), shows a brief message,
// then cuts power. Capped total duration (a few hundred ms) so a
// non-responsive radio can't hang the shutdown indefinitely.
void performGracefulShutdown() {
  Serial.println("Shutting down...");

  ScreenBuffer shutdownScreen;
  shutdownScreen.setLine(0, "Powering Off...");
  oledDisplay.render(shutdownScreen);

  UplinkPacket shutdownPacket;
  shutdownPacket.flags = UplinkPacket::kFlagShuttingDown;
  uint8_t buf[Packet::kUplinkEncodedSize];
  const size_t length =
      Packet::encodeUplink(shutdownPacket, buf, sizeof(buf));

  constexpr int kShutdownRetries = 3;
  constexpr unsigned long kShutdownRetryDelayMs = 100;
  for (int i = 0; i < kShutdownRetries; ++i) {
    if (length > 0) {
      xbeeControl.sendPacket(buf, static_cast<uint16_t>(length));
    }
    delay(kShutdownRetryDelayMs);
  }

  digitalWrite(PinAssignment::kPowerLatchHold, LOW);
  // The rail should collapse almost immediately; spin here rather than
  // falling back into loop() in an undefined half-shutdown state in case
  // it doesn't.
  while (true) {
  }
}

const char *chargeStateName(ChargeState state) {
  switch (state) {
    case ChargeState::kDone: return "done";
    case ChargeState::kCharging: return "charging";
    case ChargeState::kRecoverableFault: return "recoverable-fault";
    case ChargeState::kLatchedFault: return "latched-fault";
    default: return "unknown";
  }
}

}  // namespace

void setup() {
  // Must be the very first thing that happens: the soft-latch circuit only
  // keeps the 3.3V rail up because the power button is physically held.
  // If this pin isn't driven HIGH before the user releases the button,
  // power collapses before the rest of setup() ever runs. See
  // PCB/README.md's "Power Architecture" section.
  pinMode(PinAssignment::kPowerLatchHold, OUTPUT);
  digitalWrite(PinAssignment::kPowerLatchHold, HIGH);

  // XBee SLEEP_RQ: must be driven low (stay awake) before anything else
  // touches it — see pin_assignment.h. Harmless on boards where this pin
  // isn't wired to the XBee at all (see PCB/GPIO_table.md).
  pinMode(PinAssignment::kXbeeSleepRq, OUTPUT);
  digitalWrite(PinAssignment::kXbeeSleepRq, LOW);

  Serial.begin(115200);

  // Bring-up aid: this board has no external USB-UART bridge chip (bare
  // WROOM-1 module, see PCB/GPIO_table.md) — Serial goes over the
  // ESP32-S3's native USB-CDC peripheral, which has to fully
  // re-enumerate with the host after every reset. That consistently
  // takes longer than this firmware needs to reach its early boot
  // prints, so they were getting lost even with a monitor already open
  // and waiting -- 2000ms wasn't long enough to reliably cover a real
  // dev machine's reconnect time (observed several seconds on one
  // laptop). HWCDC's bool operator reflects the real host-connection
  // state, not just whether begin() was called.
  //
  // TODO(bring-up): this wait fires on every boot with no host attached
  // too -- i.e. every real-world power-on once this ships, not just
  // during debugging. 5s of dead time before the splash even shows up
  // is fine for now but not acceptable in the field; shorten this back
  // down (or make it conditional on something cheap to detect, like a
  // held button) before this goes to an actual user.
  constexpr unsigned long kSerialWaitMs = 5000;
  const unsigned long serialWaitStartMs = millis();
  while (!Serial && millis() - serialWaitStartMs < kSerialWaitMs) {
    delay(10);
  }

  // If the battery is already at/below the critical threshold the
  // instant the device is turned on (e.g. it sat unused long enough to
  // self-discharge), don't run a full boot — show a brief message and
  // cut power immediately rather than starting a session on a battery
  // that's already past the safe-shutdown line. No countdown here (see
  // low_battery.h): unlike the running-countdown case, no session has
  // started yet, so there's nothing to gracefully wind down.
  {
    const int rawVsysAtBoot = analogRead(PinAssignment::kVsysSense);
    const int bootBatteryPercent = batteryMonitor.percentFor(rawVsysAtBoot);
    if (bootBatteryPercent <= BatteryThresholds::kCriticalPercent) {
      Serial.println("Battery critical at boot -- powering off.");
      if (oledDisplay.begin()) {
        ScreenBuffer emptyScreen;
        renderBatteryEmptyScreen(&emptyScreen);
        oledDisplay.render(emptyScreen);
      }
      constexpr unsigned long kBatteryEmptyMessageMs = 3000;
      delay(kBatteryEmptyMessageMs);
      digitalWrite(PinAssignment::kPowerLatchHold, LOW);
      while (true) {
      }
    }
  }

  // Confirmed against real hardware during bring-up: this line idles HIGH
  // (100kOhm R_PWR_SENSE pull-up to 3V3, per PCB/power_control.kicad_sch)
  // and the switch pulls it to GND when held — active-low, same sense as
  // every other button, just via an external pull-up instead of the
  // internal one. The original active-high assumption had this backwards,
  // which read the button as continuously held from boot and triggered an
  // unwanted graceful-shutdown 3 seconds into every session.
  pinMode(PinAssignment::kPowerButtonSense, INPUT);

  // All buttons wire to GND with the internal pull-up enabled, so LOW =
  // pressed. No classification happens here — Amidala owns single/double/
  // long-press and alt semantics centrally; this firmware only reports
  // debounced raw press/release, via the uplink packet below.
  for (size_t i = 0; i < Buttons::kCount; ++i) {
    pinMode(Buttons::kPins[i], INPUT_PULLUP);
  }

  // bq25185 STAT1/STAT2: open-drain, external 10kOhm pull-up to 3V3 (see
  // PCB/GPIO_table.md) — plain INPUT, no internal pull needed.
  pinMode(PinAssignment::kChargeStat1, INPUT);
  pinMode(PinAssignment::kChargeStat2, INPUT);

  // Restores any previously-run trigger/stick calibration; defaults to an
  // uncalibrated full ADC range if none has been saved yet.
  calibrationData = CalibrationStore::load();
  menuController.setStickDeadzonePercent(calibrationData.stickDeadzonePercent);

  // Restores any previously-saved droid list; defaults to empty if none
  // has been saved yet.
  menuController.setDroidStore(DroidPersistence::load());

  // Restores any previously-saved Display Config slot assignments;
  // defaults are left in place for anything never saved.
  ComplicationPersistence::load(&complications);
  menuController.setComplications(&complications);

  // Restores any previously-saved power management settings; defaults to
  // kAlwaysOn (no behavior change) if none has been saved yet.
  powerConfig = PowerConfigStore::load();
  powerManager.setConfig(powerConfig);
  menuController.setPowerConfig(&powerConfig);

  // Absent entirely on the first production boards (see
  // PCB/GPIO_table.md's Accelerometer section) — motion just never
  // counts as activity in that case, no special-casing needed elsewhere.
  if (!accelerometer.begin()) {
    Serial.println("Accelerometer not found at boot (expected on boards "
                   "without it).");
  }

  xbeeControl.begin();

  // Bring-up diagnostic: with R_XBEE_ATTN_PU1 (10kOhm to 3V3) in place,
  // ATTN should read HIGH here (idle, no frame queued) whenever the
  // module is actually connected and powered — regardless of whether any
  // AT command below succeeds. A LOW or erratic reading instead points at
  // a physical connection problem (e.g. the module's THT socket, used
  // for prototyping per PCB/GPIO_table.md) rather than at command
  // sequencing/timing.
  Serial.print("XBee ATTN pin at boot: ");
  Serial.println(digitalRead(PinAssignment::kXbeeSpiAttn) == HIGH
                     ? "HIGH (expected idle)"
                     : "LOW (unexpected -- check module seating/wiring)");

  // A controller must join a droid's network, never form its own — CE=1
  // (coordinator) would strand it on a PAN of its own.
  switch (ensureRouterRole(&xbeeControl)) {
    case XbeeRoleResult::kSwitchedToRouter:
      Serial.println("XBee was set to coordinator; switched to router.");
      break;
    case XbeeRoleResult::kQueryFailed:
      Serial.println("XBee role (CE) query failed at boot.");
      break;
    case XbeeRoleResult::kSetFailed:
      Serial.println("XBee role (CE) could not be set to router at boot.");
      break;
    case XbeeRoleResult::kAlreadyRouter:
    case XbeeRoleResult::kNoTransport:
      break;
  }

  menuController.setXbeeTransport(&xbeeControl);

  // The XBee module remembers its own PAN ID across power cycles once
  // XbeeControl::setPanId() commits one via "WR" — it never needs to be
  // re-applied here. This just derives which saved droid (by name) that
  // PAN ID corresponds to, for the "Droid Name" complication; no match
  // (e.g. first boot, or after a Factory Reset clears the list) leaves
  // the "(none)" default in place.
  char currentPanId[17];
  if (xbeeControl.queryPanId(currentPanId, sizeof(currentPanId))) {
    const DroidStore &droidStore = menuController.droidStore();
    size_t matchIndex;
    if (droidStore.findByPanId(currentPanId, &matchIndex)) {
      menuController.setCurrentDroidName(droidStore.at(matchIndex).name);
    }
  } else {
    Serial.println("XBee PAN ID query failed at boot.");
  }

  // The module's SL is fixed hardware, so querying it once at boot (for
  // the Device Info screen) is enough — no need to re-query per menu
  // visit. deviceSerialLowBuf must outlive setup() since MenuController
  // only stores the pointer it's given, not a copy.
  if (xbeeControl.querySerialLow(deviceSerialLowBuf,
                                 sizeof(deviceSerialLowBuf))) {
    menuController.setDeviceSerialLow(deviceSerialLowBuf);
  } else {
    Serial.println("XBee SL query failed at boot.");
  }

  // Power-on splash, so it's obvious the device is booting rather than
  // just dark/unresponsive, followed by the existing brief boot
  // confirmation text — loop() takes over with the real complications
  // screen once real sensor data starts flowing.
  if (oledDisplay.begin()) {
    oledDisplay.renderBitmapCentered(SnipsLogo::kBitmap, SnipsLogo::kWidth,
                                     SnipsLogo::kHeight);
    constexpr unsigned long kBootSplashMs = 1200;
    delay(kBootSplashMs);
    showBootScreen();
  } else {
    Serial.println("OLED not found at boot.");
  }

  // Bring-up check per PCB/README.md's recommended order: cycle through
  // every status color once to prove RMT output on the real LED. Real
  // state takes over once loop() starts running (see the once-a-second
  // block below).
  rgbLed.begin();
  const SystemState bringUpSequence[] = {
      SystemState::kBooting, SystemState::kConnected,
      SystemState::kDisconnected, SystemState::kCharging,
      SystemState::kError,
  };
  for (SystemState state : bringUpSequence) {
    rgbLed.show(statusLedController.colorFor(state));
    delay(300);
  }
  rgbLed.show(statusLedController.colorFor(SystemState::kDisconnected));
}
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

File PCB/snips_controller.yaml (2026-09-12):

project:
  name: Snips Controller
  revision: 0.1
  description: >
    Wireless handheld R2-D2 controller (Snips Controller). ESP32-S3-WROOM-1
    module MCU (integrated WiFi/BT, flash, crystal, antenna — no external
    RF/flash/crystal design needed; see MCU_Core section), custom USB-C for
    flashing/charging/future accessory expansion, XBee3 Zigbee radio over
    SPI, hall effect thumbstick and analog trigger, SSD1306 OLED display,
    WS2812 RGB LED, embedded bq25185 charger + TLV62569 3.3V buck, swappable
    single-cell Li-ion battery, soft-latch power control. Macro buttons are
    direct-wired (no scan matrix) — ESP32-S3-WROOM-1 has ample spare GPIO,
    unlike the bare-RP2350A design this replaced.

# ---------------------------------------------------------------------------
# NET LEGEND
# ---------------------------------------------------------------------------
# VBUS        - 5V USB input from USB-C connector
# VSYS        - Battery/charger system output (bq25185 SYS pin), ~3.7-4.5V
# 3V3         - Regulated 3.3V output from TLV62569 buck
# GND         - Ground
# VBAT        - Battery positive terminal
# USB_DP_MCU/USB_DM_MCU - USB D+/D- data lines (native USB, U_MCU pins 14/13)
# I2C_SDA     - I2C data (pin 12) — OLED
# I2C_SCL     - I2C clock (pin 17) — OLED
# SPI_SCK     - XBee SPI clock (pin 18)
# SPI_MOSI    - XBee SPI MOSI (pin 19)
# SPI_MISO    - XBee SPI MISO (pin 20)
# XBee_CS     - XBee SPI chip select (pin 21)
# XBEE_ON_SLEEP - XBee ON/~SLEEP status, host input (pin 22)
# XBEE_SPI_ATTN - XBee SPI data-ready interrupt (pin 8)
# TRIG_ANALOG - Analog trigger output from DRV5055 (pin 4, ADC1_CH3)
# STICK_X     - Thumbstick X axis (pin 5, ADC1_CH4)
# STICK_Y     - Thumbstick Y axis (pin 6, ADC1_CH5)
# STAT1       - bq25185 charge status pin 1 (open-drain, pin 39)
# STAT2       - bq25185 charge status pin 2 (open-drain, pin 34) — combined
#               with STAT1 to fully decode charging/done/fault states
# RGB_DIN     - WS2812 NeoPixel data in (pin 37)
# PWR_EN      - TLV62569 EN signal, driven by soft latch PFET drain
# PWR_GATE    - PFET gate node (pulled HIGH by default = off)
# PWR_LATCH_G - NFET latch gate (driven by button OR PWR_HOLD)
# PWR_HOLD    - Pin 36 output to OR diode, holds latch after boot
# PWR_BTN_SENSE - Power button junction: R_BTN_PU/R_PWR_SENSE divider
#               midpoint, pulled to VSYS, button pulls to GND, feeds pin 38
# BTN_*       - Individual button nets (pulled up internally, wired to GND),
#               includes the 6 macro buttons — direct-wired, no scan matrix
# MCU_EN      - EN (reset) pin, pulled up via R_EN_PU
# MCU_BOOT    - GPIO0/BOOT strapping pin, pulled up via R_BOOT_PU, button
#               pulls low to enter UF2/download mode
# VSYS_SENSE  - Divide-by-3 VSYS sense into pin 7 (ADC1_CH6), via
#               R_VSYS1/R_VSYS2

# ---------------------------------------------------------------------------
# RESERVED GPIO — DO NOT USE
# ---------------------------------------------------------------------------
# Pin 3  (EN)      - reset/enable, pulled up via R_EN_PU
# Pin 27 (GPIO0)   - BOOT strapping pin, pulled up via R_BOOT_PU + button
# Pin 13 (GPIO19)  - USB_D-  (native USB)
# Pin 14 (GPIO20)  - USB_D+  (native USB)
# Pins 1, 40, 41   - GND
# Pin 2            - 3V3
#
# Use with care if ever needed (strapping pins, sampled at boot):
# Pin 15 (GPIO3), Pin 16 (GPIO46), Pin 26 (GPIO45)
#
# Spare (clean, no caveats) — default JTAG, fully reusable as plain GPIO:
# Pin 32 (GPIO39/MTCK), Pin 33 (GPIO40/MTDO), Pin 34 (GPIO41/MTDI),
# Pin 35 (GPIO42/MTMS)
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

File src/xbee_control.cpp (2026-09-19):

#include "xbee_control.h"

namespace {

int hexNibble(char c) {
  if (c >= '0' && c <= '9') return c - '0';
  if (c >= 'A' && c <= 'F') return c - 'A' + 10;
  if (c >= 'a' && c <= 'f') return c - 'a' + 10;
  return -1;
}

// Parses exactly byteCount*2 hex characters from hex into outBytes.
// Returns false (leaving outBytes untouched) on any non-hex character or
// a string shorter than expected.
bool hexStringToBytes(const char *hex, uint8_t *outBytes, size_t byteCount) {
  for (size_t i = 0; i < byteCount; i++) {
    const int hi = hexNibble(hex[i * 2]);
    const int lo = hi >= 0 ? hexNibble(hex[i * 2 + 1]) : -1;
    if (hi < 0 || lo < 0) return false;
    outBytes[i] = static_cast<uint8_t>((hi << 4) | lo);
  }
  return true;
}

void bytesToHexString(const uint8_t *bytes, size_t byteCount, char *outHex) {
  constexpr char kDigits[] = "0123456789ABCDEF";
  for (size_t i = 0; i < byteCount; i++) {
    outHex[i * 2] = kDigits[bytes[i] >> 4];
    outHex[i * 2 + 1] = kDigits[bytes[i] & 0x0F];
  }
  outHex[byteCount * 2] = '\0';
}

}  // namespace

bool XbeeControl::leaveNetwork() {
  // "NR0": local network reset — forces the module to leave its current
  // network and search again per its (about-to-change) ID setting.
  uint8_t value[] = {0};
  return spi_.sendAtCommand("NR", value, sizeof(value), nullptr, 0, nullptr);
}

bool XbeeControl::setPanId(const char *panId) {
  uint8_t panIdBytes[8];
  if (!hexStringToBytes(panId, panIdBytes, sizeof(panIdBytes))) {
    return false;
  }
  if (!spi_.sendAtCommand("ID", panIdBytes, sizeof(panIdBytes), nullptr, 0,
                          nullptr)) {
    return false;
  }
  // "WR": commit to the module's own flash. Once written, the module
  // remembers this PAN ID across power cycles on its own — nothing needs
  // to re-apply it at boot, and it never changes again until this method
  // is called again for a different droid.
  return spi_.sendAtCommand("WR", nullptr, 0, nullptr, 0, nullptr);
}

bool XbeeControl::rejoinNetwork() {
  // "AC": apply pending parameter changes now, triggering the module to
  // act on the new ID and (re)associate rather than waiting for its next
  // natural re-read of that setting.
  return spi_.sendAtCommand("AC", nullptr, 0, nullptr, 0, nullptr);
}

bool XbeeControl::queryCoordinatorEnable(uint8_t *outValue) {
  uint8_t value[1];
  uint8_t valueLength = 0;
  if (!spi_.sendAtCommand("CE", nullptr, 0, value, sizeof(value),
                          &valueLength) ||
      valueLength != sizeof(value)) {
    return false;
  }
  *outValue = value[0];
  return true;
}

bool XbeeControl::setCoordinatorEnable(uint8_t value) {
  if (!spi_.sendAtCommand("CE", &value, sizeof(value), nullptr, 0, nullptr)) {
    return false;
  }
  // "WR" so the role survives power cycles, "AC" so it takes effect now.
  return spi_.sendAtCommand("WR", nullptr, 0, nullptr, 0, nullptr) &&
         spi_.sendAtCommand("AC", nullptr, 0, nullptr, 0, nullptr);
}

bool XbeeControl::querySerialLow(char *outHex, size_t outHexCapacity) {
  if (outHexCapacity < 9) {
    return false;  // 8 hex chars + null
  }
  uint8_t value[4];
  uint8_t valueLength = 0;
  if (!spi_.sendAtCommand("SL", nullptr, 0, value, sizeof(value),
                          &valueLength) ||
      valueLength != sizeof(value)) {
    return false;
  }
  bytesToHexString(value, sizeof(value), outHex);
  return true;
}

bool XbeeControl::queryPanId(char *outHex, size_t outHexCapacity) {
  if (outHexCapacity < 17) {
    return false;  // 16 hex chars + null
  }
  uint8_t value[8];
  uint8_t valueLength = 0;
  if (!spi_.sendAtCommand("ID", nullptr, 0, value, sizeof(value),
                          &valueLength) ||
      valueLength != sizeof(value)) {
    return false;
  }
  bytesToHexString(value, sizeof(value), outHex);
  return true;
}

bool XbeeControl::queryLocalRssiDbm(int *outDbm) {
  uint8_t value[1];
  uint8_t valueLength = 0;
  if (!spi_.sendAtCommand("DB", nullptr, 0, value, sizeof(value),
                          &valueLength) ||
      valueLength != sizeof(value)) {
    return false;
  }
  *outDbm = -static_cast<int>(value[0]);
  return true;
}

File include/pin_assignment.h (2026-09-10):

#pragma once

// Raw GPIO pin assignments for the Snips Controller (ESP32-S3-WROOM-1).
// Values here are Arduino GPIO numbers (e.g. 16 means GPIO16), not the
// module's physical pin numbers used in the PCB docs.
//
// This file is pure reference data — it should stay a 1:1 mirror of
// PCB/GPIO_table.md. Cross-reference that file for the physical-pin-to-GPIO
// mapping, reserved pins, and the rationale behind each assignment.

namespace PinAssignment {

// ---- SPI (XBee) --------------------------------------------------------
constexpr int kXbeeSpiSck = 10;
constexpr int kXbeeSpiMosi = 11;
constexpr int kXbeeSpiMiso = 12;
constexpr int kXbeeSpiCs = 13;
constexpr int kXbeeOnSleep = 14;
constexpr int kXbeeSpiAttn = 15;
// XBee DTR/SLEEP_RQ, driven by the host to request pin sleep (drive high =
// request sleep once idle, low = wake immediately). Was hardwired to GND
// (permanently deasserted) on earlier revisions; must be set to a known
// level (low = stay awake) as one of the first instructions in setup(),
// same idiom as kPowerLatchHold, since it's replacing a hard GND tie
// rather than a pull resistor.
constexpr int kXbeeSleepRq = 42;

// ---- I2C (OLED, QMA6100P accelerometer) ----------------------------------
constexpr int kI2cSda = 8;
constexpr int kI2cScl = 9;

// ---- Accelerometer (QMA6100P, shares the I2C bus above) ------------------
// INT1 output, wired so the MCU can light-sleep and wake on the
// accelerometer's hardware any-motion/no-motion interrupt instead of
// polling. Strapping pin (GPIO46, boot message control only) — safe here
// since the accelerometer's interrupt output stays inactive through boot
// until firmware configures it.
constexpr int kAccelInterrupt = 46;

// ---- ADC1 (analog trigger, thumbstick, battery sense) -------------------
constexpr int kAnalogTrigger = 4;
constexpr int kThumbstickX = 5;
constexpr int kThumbstickY = 6;
constexpr int kVsysSense = 7;

// ---- Digital buttons -----------------------------------------------------
// "Vol" and "Trigger" up/down are two generic, symmetric button pairs —
// see PCB/GPIO_table.md. What each pair does is assigned by Amidala, not
// fixed in firmware; these names just match the PCB's schematic/net names.
constexpr int kVolUp = 40;
constexpr int kVolDown = 39;
constexpr int kTriggerUp = 16;
constexpr int kTriggerDown = 17;
constexpr int kDigitalTrigger = 18;  // bumper
constexpr int kThumbstickClick = 21;
constexpr int kMacro1 = 47;
constexpr int kMacro2 = 48;
constexpr int kMacro3 = 35;
constexpr int kMacro4 = 36;
constexpr int kMacro5 = 37;
constexpr int kMacro6 = 38;

// ---- Power ---------------------------------------------------------------
constexpr int kPowerButtonSense = 2;
constexpr int kPowerLatchHold = 44;

// ---- Charging (bq25185) ---------------------------------------------------
constexpr int kChargeStat1 = 1;
constexpr int kChargeStat2 = 41;

// ---- RGB status LED (SK6812/WS2812, RMT-driven) ---------------------------
constexpr int kRgbLedData = 43;

}  // namespace PinAssignment

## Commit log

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2026-08-18 refactor: switch over to esp32-s3-wroom1 (#13)
    This refactors to the esp32-s3 to avoid every problem we encountered with the raspberry pi options.
    [battery.kicad_sch, button_matrix.kicad_sch, buttons_direct.kicad_sch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]
2026-08-18 refactor: migrate firmware/tests/CI from KB2040 to ESP32-S3-WROOM-1 (#14)
    The bare firmware, native test suite, and CI build target were still
    built around the KB2040 (RP2040) from before the PCB refactor to
    ESP32-S3-WROOM-1. Update the PlatformIO env, CI job, and GPIO pin
    assignments to match the current hardware (PCB/GPIO_table.md), and
    drop the RP2040-specific UART0/GPIO0-1 pin-stealing workaround that
    ESP32-S3's remappable UART pins no longer need.
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2026-08-22 Fix footprints and begin layout (#17)
    * refactor: updated gulikit footprint
    This updates the gulikit thumbstick footprint to be accurate.
    * layout: beginning pcb layout
    This updates the schematic with a few different footprints while also starts the layout.
    [battery.kicad_sch, buttons_direct.kicad_sch, hall_trigger.kicad_sch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]
2026-08-22 refactor: swap footprints and add symmetry (#18)
    This updates the footprints of a couple components to be smaller and closer to what we want. It also adds two buttons to ensure left and right side symmetry.
    [battery.kicad_sch, buttons_direct.kicad_sch, hall_trigger.kicad_sch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]
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2026-08-24 refactor: flipped hall sensor to back side (#28)
    This is a better position for the hall trigger anyway.
    [snips_controller-B_Cu.gbr, snips_controller-B_Mask.gbr, snips_controller-B_Paste.gbr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]
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2026-08-28 fix: add pull-up on XBee SPI_ATTN pin (#30)
    SPI_ATTN doubles as the XBee3's BOOTMODE strap; Digi's hardware
    reference manual (doc 90001543) says not to let it be tied/pulled low
    at reset. R_XBEE_ATTN_PU1 (10kΩ to 3V3) holds it high before firmware
    configures the pin, matching the existing R_XBEE_RST1 pull-up pattern
    on RESET.
    Verified via kicad-cli: the new resistor lands on the XBEE_SPI_ATTN
    net alongside U_XBEE1 pin 19 and the MCU's GPIO15, and ERC is clean.
    [snips_controller-B_Cu.gbr, snips_controller-B_Mask.gbr, snips_controller-B_Paste.gbr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]
2026-08-28 task: add JLCPCB/LCSC part-matching script (#31)
    * task: add JLCPCB/LCSC part-matching script
    Looks up every BOM line's Manufacturer + MPN (fields every part in this
    project already carries) against JLCPCB's public component-search
    endpoint -- the same one jlcpcb.com's own search box uses, no API key
    needed -- and reports the matched LCSC part number.
    Report-only for now: it doesn't touch the schematic. 31/33 parts on the
    board matched automatically in testing; the 2 misses (C_BUCK_OUT1,
    R_ISET1) genuinely aren't in JLC's catalog under those exact Yageo part
    numbers, confirmed by zero search results, not a matching bug.
    * task: writ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
    [battery.kicad_sch, buttons_direct.kicad_sch, hall_trigger.kicad_sch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]
2026-08-29 fix: swap 3 JLCPCB-out-of-stock parts for in-stock equivalents (#32)
    C_BAT1/C_BUCK_IN1/C_OLED_1/C_SYS_1/C_VIN_1 (10uF 0805 X5R 16V):
    Yageo CC0805KRX5R7BB106 was at 0 stock -> HRE CGA0805X5R106K160MT
    (LCSC C6119886, stock ~254k). Identical spec, different brand.
    D_VBUS_TVS1: Nexperia PESD5V0S1BA,115 was down to 1 in stock -> TECH
    PUBLIC TPPESD5V0S1BA (LCSC C587144, stock ~981k), a widely-stocked
    pin/spec-compatible clone of the same part, same SOD-323 package.
    Q_PWR1: Diodes Inc DMG2305UX-7 was down to 8 in stock -> Diodes Inc
    DMG2305UX-13 (LCSC C144153, stock ~25k) -- same manufacturer, same
    part, the -7/-13 suffix is just reel size (7"/13"), not an electrical
    variant.
    Found via live JLCP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
    [oled.kicad_sch, power_buck.kicad_sch, power_charger.kicad_sch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]
2026-08-29 task: alert on Basic-library alternatives during JLC part matching (#33)
    * task: alert on Basic-library alternatives during JLC part matching
    JLC's "Extended" library carries a per-unique-part setup fee on top of
    unit price; "Basic" doesn't. That fee doesn't amortize well on a board
    with many distinct low-quantity parts -- confirmed the hard way: our
    first real JLCPCB assembly quote came back at $333.84 vs PCBWay's
    ~$190 for the same order, and all 33 of our matched parts were
    Extended.
    jlc_match.py now does a secondary search for a same-value/same-package
    Basic-library part whenever the real match lands on Extended, and
    flags it in the report (new BasicAlt column + a Status alert) rather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
    [hall_trigger.kicad_sch, mcu_core.kicad_sch, oled.kicad_sch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]
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2026-09-07 chore: commit stale used_designators cache reorder in kicad_pro (#37)
    Pure KiCad-internal bookkeeping (the used_designators cache reordered
    itself, same designator set) left dirty in the working tree from before
    this session. No actual design change — committing it just to clear the
    noise from git status going forward.
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2026-09-07 feat: drive RGB status LED from system state (PR 4/9) (#39)
    Adds the SK6812 status LED per PCB/GPIO_table.md (pin 37, RMT-driven).
    Same split as the OLED work in PR 3: StatusLedController
    (status_led.h/.cpp) is pure logic mapping SystemState
    (booting/connected/disconnected/charging/error) to an RGB color, fully
    unit tested; RgbLed (rgb_led.cpp) is a thin Adafruit_NeoPixel adapter
    that just shows whatever color it's given. rgb_led.cpp joins the native
    build/coverage exclusion list alongside oled.cpp.
    SnipsController.ino cycles through every status color once at boot —
    the bring-up check PCB/README.md's recommended order calls for ("verify
    RMT output on pin 37, cycle colors") — then settl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
    [SnipsController.ino]
2026-09-08 feat: battery/charge status and analog trigger+stick calibration (PR 5/9) (#40)
    Bundles three subsystems that are all "ADC reading + calibration," the
    same shape of problem:
    - BatteryMonitor (battery.h/.cpp): raw VSYS ADC -> battery percentage,
    via the R_VSYS1/R_VSYS2 divide-by-3 network and a linear approximation
    between empty/full cell voltage (documented as a v1 simplification of
    a real Li-ion discharge curve). Charge-state decoding from STAT1/STAT2
    is pulled directly from the bq25185 datasheet's (SLUSF65A) Table 7-2
    "Status Pins State Table" rather than guessed.
    - AnalogCalibration (calibration.h/.cpp): raw trigger/stick ADC ->
    calibrated 0-100 / -100..100, using stored min/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
    [SnipsController.ino, battery.h]
2026-09-08 feat: on-device menu core, Device Info, Factory Reset (PR 6/9) (#41)
    Adds the on-device menu system: hold Left Up+Down together for 1s to
    open it, then Left Up/Down scroll, Stick Click confirms, Bumper backs
    out. All pure logic — MenuController (menu.h/.cpp) knows nothing about
    real buttons or the display; SnipsController.ino translates button
    edges into its four nav calls, and renderMenuScreen() turns menu state
    into a ScreenBuffer for the existing OledDisplay to draw.
    Menu tree covers everything that's genuinely local and has everything
    it needs already built:
    - Calibrate Stick / Calibrate Trigger — wires up the guided-calibration
    flows built in PR 5 (previously unused), persisting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
    [SnipsController.ino, menu.h]
2026-09-08 feat: droid management (switch/manage droids) (PR 7/9) (#42)
    Adds Switch Droid and Manage Droids to the menu tree, completing it —
    these were the two items deferred out of PR 6 pending this subsystem.
    - DroidStore (droid_store.h/.cpp): pure in-memory name+PAN ID list,
    add/remove, capacity-bounded. DroidPersistence (droid_persistence.cpp)
    is the thin NVS adapter, joining the native build/coverage exclusion
    list alongside calibration_store.cpp.
    - DroidSwitcher + XbeeTransport (xbee_control.h/.cpp): pure orchestration
    of the leave/set-PAN/rejoin sequence, tested against a fake transport.
    XbeeControl is an honest stub reporting failure for every step — the
    real XBee SPI/AT-comma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
    [SnipsController.ino, menu.h]
2026-09-08 feat: real XBee SPI transport and local AT commands (PR 8/10) (#43)
    First functional radio link: replaces the XbeeControl stub from PR 7
    with a real implementation talking to the XBee3 over SPI, and splits
    this PR out of the original PR 8 (transport + packet protocol) per the
    rewrite plan's own contingency — this alone is big enough on its own.
    The custom uplink/downlink state-report schema is now PR 9, and the
    final complications/handedness/shutdown work becomes PR 10.
    - xbee_frame.h/.cpp: pure XBee API frame logic — checksum compute/
    validate, and AT Command (0x08) / AT Command Response (0x88) frame
    build/parse. Round-trip tested.
    - xbee_spi.cpp: thin SPI adapter (3MHz/MSB-first/m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
    [SnipsController.ino, menu.h, xbee_control.cpp]
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2026-09-08 fix: persist PAN ID selection correctly, disconnect radio on Factory Reset (#46)
    * fix: persist and reapply the currently-selected droid's PAN ID
    Switching droids previously only updated the radio's in-RAM ID setting
    and an in-memory display name — neither survived a power cycle, so the
    controller wouldn't reliably reconnect to the last-selected droid after
    a reboot. The droid *list* was already persisted; which one is
    currently active was not.
    - droid_persistence.h/.cpp gains saveCurrentSelection()/
    loadCurrentSelection()/clearCurrentSelection(), in their own NVS
    namespace separate from the list — DroidPersistence::save() calls
    prefs.clear() on the list's namespace every time it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
    [SnipsController.ino, menu.h, xbee_control.cpp]
2026-09-10 Accelerometer-driven low-power mode (hardware, PCB only) (#47)
    * feat: accelerometer-driven low-power mode (hardware, PCB 1/2)
    Adds a QMA6100P accelerometer (I2C, shared OLED bus) and enables
    host-commanded XBee pin-sleep, laying the hardware groundwork for a
    low-power mode: OLED off + XBee sleep after a short idle timeout (no
    buttons, no motion), full soft-latch power-off after a longer one.
    - QMA6100P chosen after checking JLCPCB's actual parts library: no
    candidate accelerometer is Basic-library, so it won on price, size,
    and standby current (500nA), which matters since it has to watch for
    motion through the whole low-power period.
    - Hand-authored symbol + footprint (no existing l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
    [accelerometer.kicad_sch, mcu_core.kicad_sch, power_charger.kicad_sch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]
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2026-09-12 fix: correct SK6812 RGB LED footprint mismatch that failed PCBWay assembly (#49)
    D_RGB1 was still using a stale generic 5.0x5.0mm PLCC4 footprint left
    over from before the design switched to the SK6812MINI-E, which is what
    PCBWay's assembly check caught. Added a custom footprint sourced from
    the real OPSCO SK6812MINI-E-012 datasheet, pointed the schematic at it,
    and reworked the PCB placement/routing to match. DRC clean, 0 unconnected.
    [rgb_led.kicad_sch, snips_controller.kicad_pcb, snips_controller.yaml]
2026-09-19 fix: pad short PAN IDs for the XBee, and force router role at boot (#50)
    * fix: pad short PAN IDs for the XBee, and force router role at boot
    Short PAN IDs (e.g. "4133") could be saved and displayed, but switching
    to one failed with "Set PAN failed": XbeeControl::setPanId requires
    exactly 16 hex digits and rejected it before sending anything. The
    boot-time droid-name lookup also strcmp'd the saved "4133" against the
    module's zero-padded "0000000000004133", so it never matched.
    - Add PanId::normalize/equivalent (pure, tested): uppercase + left-pad
    to 16 digits.
    - DroidSwitcher pads before calling the transport; invalid IDs now
    report "Invalid PAN ID" without touching the network.
    - Droi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
    [SnipsController.ino]
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2026-09-23 fix: resolve first-board bring-up issues (power, OLED, XBee diagnostics, button naming) (#53)
    Found and fixed during hands-on bring-up of the first assembled board:
    - Power-button-sense polarity was inverted (assumed active-high, actually
    active-low via an external pull-up) -- read the button as continuously
    held from boot and triggered an unwanted graceful shutdown 3s into every
    session.
    - OledDisplay could crash (StoreProhibited/null-buffer write) whenever the
    display wasn't present, because Adafruit_SSD1306::begin() never
    allocates its frame buffer unless its own begin() is called, and nothing
    else in the call chain checked readiness before rendering. Added a real
    I2C prese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
    [oled.kicad_sch]
2026-09-23 feat: stick-as-nav, configurable deadzone, and menu bug fixes from hardware bring-up (#54)
    Found and fixed during continued hands-on testing of the on-device menu:
    - Left Up/Down and Right Up/Down were mapped to the physically wrong
    button pairs (Vol/Trigger swapped) -- confirmed against the real
    controller and corrected in Buttons::kPins.
    - Stick calibration's confirm step used Stick Click, which risks nudging
    the stick right as its center/extreme position is being captured, and
    there's no button actually labeled "Enter" on this controller --
    switched calibration screens to confirm with Macro1 instead.
    - The droid-naming screen had zero on-screen instructions and Bumper
    would b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
    [SnipsController.ino, menu.h]
2026-09-23 fix: silence false-alarm boot log errors from NVS and accelerometer probe (#55)
    - All four persistence load() functions (CalibrationStore,
    DroidPersistence, ComplicationPersistence, PowerConfigStore) opened
    their Preferences namespace read-only, which makes nvs_open() fail
    with NOT_FOUND (logged as an alarming error) on a device that's never
    saved that namespace yet -- true on every first boot. Opening
    read-write instead silently creates the empty namespace; no behavior
    change to what's actually loaded (still falls back to defaults),
    just no more false "hardware is broken" errors.
    - Accelerometer::begin() now does a plain presence probe (address-only
    write, real stop conditio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
    [accelerometer.cpp]
2026-09-24 fix: power-latch false-trigger, RGB LED footprint regression, JST connector clarity (#56)
    Power latch: battery-only bring-up showed the board powering on immediately
    with no button press, because PWR_BTN_SENSE's resistor divider idled at
    ~VSYS/2, forward-biasing D_OR1's anode directly. Adds a transistor inverter
    (R_INV_BASE1 / Q_INV1 / R_INV_PU1) so only an actual button press can
    forward-bias D_OR1; removes the now-unnecessary R_PWR_SENSE1. New parts
    matched to JLCPCB Basic-library equivalents. PCB layout, diagrams, and
    power_control_layout docs updated to match.
    RGB LED: fixes a regression where D_RGB1's Footprint had reverted to the
    stale large SK6812 PLCC4 part in both the cached lib_sy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
    [battery.kicad_sch, oled.kicad_sch, power_control.kicad_sch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]
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2026-09-24 fix: latch gate-drive divider, floating buck EN, and missing accelerometer MPNs (#58)
    Power latch, round 2 (found via cross-checking a third-party static-analysis
    tool run against this project's own netlist and real component datasheets):
    - R_LATCH_G1 raised 10kΩ -> 1MΩ. The prior value formed an unintended divider
    with R_INV_PU1 across D_OR1, leaving only ~0.3V at Q_LATCH1's gate on a
    press -- nowhere near enough to turn it on, meaning last round's inverter
    fix likely didn't actually latch on real hardware. Raising the pull-down
    instead of shrinking the pull-up avoids turning Q_INV1's idle state into a
    continuous mA-scale drain.
    - R_INV_BASE1 repurposed from a series resistor (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
    [accelerometer.kicad_sch, power_control.kicad_sch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]
2026-09-24 fix: keep button-sense within MCU rail, and add latch-gate margin at low battery (#59)
    Both found by cross-checking a friend's static-analysis tool against our own
    netlist and datasheets.
    - R_BTN_PU1 now pulls up to 3V3 instead of VSYS. PWR_BTN_SENSE lands
    directly on GPIO2, whose ceiling is VDD+0.3V (~3.6V), but idled at VSYS
    (up to ~4.5V on USB). It also back-fed the unpowered 3V3 rail through the
    pin's clamp diode when the MCU was off. Safe now that R_INV_BASE1 gives the
    inverter its own VSYS pull-up, so R_BTN_PU1 no longer supplies it. A
    divider can't work across the 3.0-4.5V VSYS range (needs >=2.5V to read
    high but <=3.6V max).
    - Q_LATCH1 swapped 2N7002 -> AO3400A. With re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
    [power_control.kicad_sch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]
2026-09-24 fix: add C_LATCH_G1 to stop a ~2ms PWR_EN blip on battery insertion (#60)
    * fix: add C_LATCH_G1 to stop a ~2ms PWR_EN blip on battery insertion
    There's no physical board yet, so this was found by simulating the
    button/inverter/latch circuit in ngspice (KiCad's bundled libngspice) after a
    validator run claimed the board would power itself on. That claim doesn't hold
    (off-state base sits ~0.6-0.7V because the button node is only grounded
    through R_BTN_PU1, and a fast 3V3 collapse at shutdown never lifts the latch
    gate), but the simulation did show a real, minor transient: on battery
    insertion Q_INV1 isn't conducting until C_DBNC1 charges through D_INV_ISO1, so
    PWR_LATCH_G briefly rises to ~VS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
    [power_control.kicad_sch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]
2026-09-24 fix: make every BOM Value unambiguous for the fab, and switch D_INV_ISO1 to SOT-323 (#61)
    * fix: make every BOM Value unambiguous for the fab, and switch D_INV_ISO1 to SOT-323
    PCBWay flagged D_INV_ISO1: "BAT54W" is SOT-323 from nearly every maker, but we
    had picked Yangjie's SOD-123 variant. A fab only sees Designator, Footprint,
    Quantity and Value in the BOM (never MF/MPN/LCSC), so a bare part name is
    ambiguous. Fixes the class of problem, not just this part:
    - Every component's Value is now "<label> | <MPN> | <manufacturer> | <package>"
    (label dropped when it repeats the MPN; commas/periods stripped so the CSV
    never needs quoting). BT1 keeps its RIGHT-ANGLE HORIZONTAL note. Applied t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
    [accelerometer.kicad_sch, battery.kicad_sch, buttons_direct.kicad_sch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]
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2026-10-24 Remove the misleading XBee ATTN boot diagnostic (#75)
    At power-up the XBee queues a modem status frame, so ATTN is
    legitimately low when setup() samples it right after begin(). The
    "LOW (unexpected -- check module seating/wiring)" message fired on
    working hardware: the PAN ID and SL queries that follow succeed, and the
    AT command path already skips that queued frame.
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2026-10-25 Fix accelerometer INT1 polarity so low-power mode can go idle (#78)
    * Fix accelerometer INT1 polarity so low-power mode can go idle
    INTPIN_CONF (0x20) was written as 0x02 on the belief that bit 1 is
    INT1_LVL. Per the QMA6100P datasheet, bit 0 is INT1_LVL and bit 1 is
    INT1_OD, so 0x02 made INT1 open-drain and active-low. GPIO46 has no
    pull-up, so the released pin floated, read HIGH as constant motion, and
    the idle timer never advanced: no dim, no display off, no XBee sleep.
    The log showed "Activity: motion" once because it only prints rising
    edges.
    - Write 0x05 (INT1 active-high push-pull; also the reset default).
    - Move the QMA6100P register constants into qma6100p_registers.h so a
    nativ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
2026-10-25 Brightness settings, Never options for power stages, darker dim, USB status (#79)
    * Add screen and LED brightness settings, kept on wake
    - New Brightness menu (after Display Config) with Screen and LED rows.
    The LED row moves there from Power Management; both values live in
    PowerConfig and save through the existing Power Config path.
    - Screen brightness Low / Medium / High sets the SSD1306 contrast (High
    is 0xCF, the old default). The dim tier still drops to contrast 0, but
    waking now returns to the user's level instead of Adafruit_SSD1306's
    fixed default, which dim(false) always restored. Changes apply
    immediately, at boot, and when the low-battery countdown forces the
    screen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
2026-10-25 fix: update shell for clearances (#80)
    Also adds a full width L bracket to the top of the OLED housing
    to hold the OLED in place.
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2026-10-26 Update the Stackup library pin to 9cf54c6 (#83)
    Moves the parts library from 9120a03 to its current head. The only
    change in between is the SK6812MINI-E part, which this board no longer
    uses (it has the SK6812MINI-HS from parts.kdl). The CLI and KiCad
    plugin were already on the latest release, 0.2.0.
2026-10-26 Replace QMA6100P accelerometer with ICM-42670-P 6-axis IMU (#82)
    * Replace QMA6100P accelerometer with ICM-42670-P 6-axis IMU
    Swap U_ACCEL1 (QST QMA6100P) for U_IMU1, a TDK ICM-42670-P gyroscope +
    accelerometer in LGA-14 2.5x3mm, wired per DS-000451 Rev 1.1 Figure 5:
    I2C at 0x68 (AP_AD0 low), AP_CS to 3V3, FSYNC and RESV to GND, INT1 on
    GPIO46 as before. Decoupling follows Table 10 (100nF + 2.2uF on VDD, 10nF
    on VDDIO). The footprint is KiCad's stock LGA-14 3x2.5mm, checked
    against the package drawing.
    Firmware probes for the ICM-42670-P first and falls back to the
    QMA6100P, so V1.2 and earlier boards keep working. The ICM path sets up
    wake-on-motion on INT1 (latched, push-pull, active-hig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
2026-10-26 fix: tweaks to the shell to make them more functional (#84)
    this updates several components to make them a bit more printable and functional. It specifically fixes some tolerances to make things move and slide better.
2026-10-27 feat: shell battery panel, lip, power button, antenna pockets (#85)
    * feat: shell battery panel, lip, power button, antenna pockets
    - Drop-in flat battery panel with snap arms and thumb pocket
    - Stronger BottomShell alignment lip (thicker, shorter) and clean lip ends
    with a smooth swept corner on the TopShell
    - Power button: single flat flange plus diagonal stem, front fillet; TopShell
    power pocket narrowed to a slot that follows the button
    - Antenna pockets on both inner side walls of the TopShell (10x50x1 U.FL)
    - Restore the rear screw counterbores on the BottomShell
    - Regenerated export and print STL/STEP files, print README and orientation
    tooling, and shell/fusion/SnipsShell.f3d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
2026-10-28 shell: print-ready shell revision (trigger spring, M2x12 wells, simple bumper, support blocks) (#86)
    - Trigger: torsion spring channels, hook pockets and coil relief; hinge-hole end strips cut flush; 45 deg spring-ear gusset so it prints support-free
    - Face caps: flange widened to the full cap width, slightly more proud
    - BottomShell: M2 x 12 screw wells, wider battery-panel tab slot
    - Side plates and power plate: fit tweaks; power opening wider
    - Bumper rebuilt as a flat button installed from inside, side flanges only, shorter posts, 1 mm front fillet; TopShell post holders shortened with quarter-ring rests
    - Top-shell split print variants removed (single piece prints better)
    - TopShell/Bot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
2026-10-28 shell: export the filleted bumper (print STL/STEP, f3d) and drop the front block from the TopShell buck (#87)
    The print BumperCap files and f3d were missing the 1 mm button fillet. The TopShell_with_buck block outside the shell under the OLED housing is removed.
    Claude-Session: https://claude.ai/code/session_011hGoLJeZxtuwqpPbdX38rp
2026-10-29 Shell/front screw posts (#88)
    * shell: TopShell front screw posts - clear pilot holes, 3 mm radius, tidy arm undersides
    - The front PCB screw posts had a solid cutting across the pilot hole; cut clean 1.7 mm holes through both posts
    - Post outer radius 2.2 -> 3.0 mm to take the screw load; small relief at the +x post foot for the 0402 resistor next to it
    - Arm undersides lifted 0.7 mm above the PCB (replaces the one-sided resistor notch on the -x arm), arm root wedge cleaned up
    - Re-exported STEP/STL/print files (TopShell block regenerated) and f3d
    * shell: rem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

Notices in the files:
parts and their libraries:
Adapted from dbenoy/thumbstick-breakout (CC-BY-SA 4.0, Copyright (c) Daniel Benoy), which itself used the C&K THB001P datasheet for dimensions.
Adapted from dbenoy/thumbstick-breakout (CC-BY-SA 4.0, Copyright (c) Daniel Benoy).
